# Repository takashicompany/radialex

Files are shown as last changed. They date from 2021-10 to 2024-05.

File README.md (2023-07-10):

# Radialex

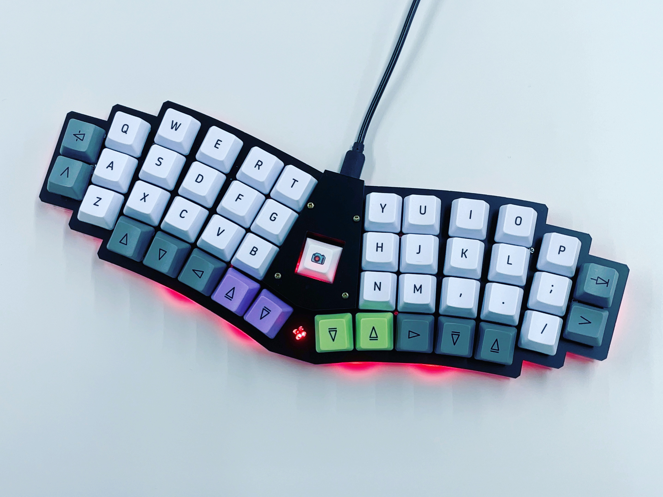
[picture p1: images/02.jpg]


Radialex(ラディアレックス)は一体型の40%のキーボードです。  
放射状に規則的に配置されたキーレイアウトは手を自然な体勢のまま置くことができ、ホームポジションから最短距離で文字を打つことを可能としています。  
キーボードの中央部にはシンボルとしてのキーやキーキャップを配置することができ、またバックライトLEDによるライトアップがされます。  
オプションでMXソケットによるキースイッチの取り替えや、LED、コンスルーにも対応しており、使用するスタイルにあわせた組み立てが可能です。  
また、ファームウェアがVIA(Remap)に対応しているため、Webブラウザからキーマップを書き換えることが可能です。



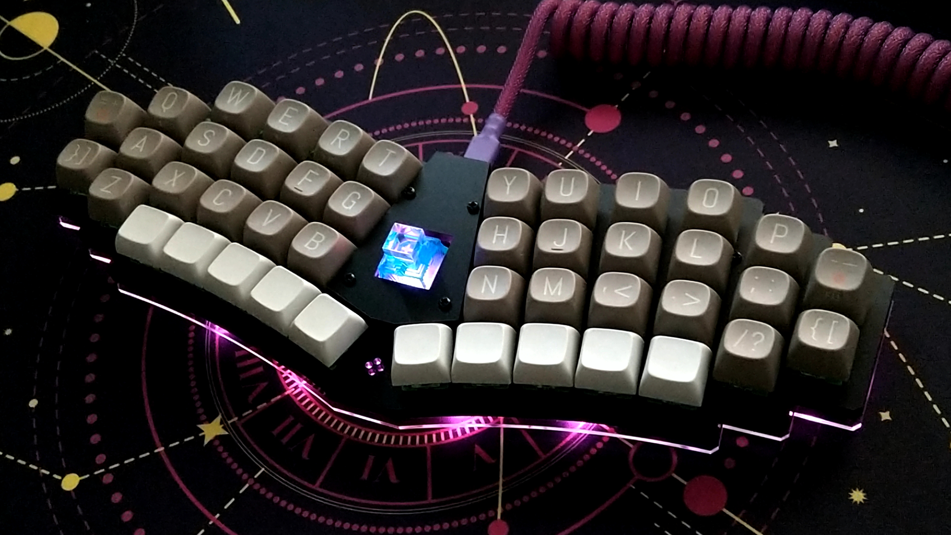
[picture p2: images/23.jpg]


## Store
- [遊舎工房](https://shop.yushakobo.jp/products/3350)
- [Booth](https://takashicompany.booth.pm/items/3394593)

## ガーバーデータ、ケースのデータについて
ご自由にご利用ください。  
尚、ガーバーデータとケースのデータをご自身で利用された際に発生した不都合に関しての責任は負いかねます。

### ガーバーデータやケースを利用した例

[@morecat_lab
](https://twitter.com/morecat_lab)さんの[3Dプリンター製のケース](https://github.com/kuwatay/radialex-3dprint-case)  


## 必要な部品

### キットに同梱されているもの
|部品|個数|備考|
|:--|:--|:--|
|PCB|1|リードタイプと表面実装のダイオードに対応。|
|トッププレート|1||
|ボトムプレート|1||
|中央トッププレート|1||
|中央積層プレート|1||
|表面実装ダイオード|45||
|m2スペーサー(シルバー5mm)|8||
|m2ネジ(シルバー4mm)|8||
|m2ネジ(シルバー8mm)|4||
|m2ネジ(ゴールド18mm)4||
|リセットスイッチ|1||
|キースイッチソケットMX用|1||
|滑り止めシール|6||

### 別途用意するもの
|部品|個数|備考|
|:--|:--|:--|
|キースイッチ|45|Cherry MX互換のもの。|
|キーキャップ|45|全て1u。Chery MX互換のもの。|
|Pro Micro|1||
|USBケーブル|1|Pro MicroとPCを接続します。|

### オプション
|部品|個数|備考|
|:--|:--|:--|
|コンスルー|2|12pin、13pinに対応しておりますのでMCU(Pro Micro)にあわせて選択が可能です。|
|MXソケット|44|中央のキー以外は、キースイッチのはんだ付け/MXソケットによる挿し込みの両方に対応。|
|LED(SK6812MINI-E)|2|中央のキーとキーボード手前側の穴をバックライトで光らせることができます。|
|LED(WS2812B)|10|アンダーグロウライトとしてキーボードの底面を光らせることができます。|

## 組みたて方

[Rev1の組み立て方はこちら](https://github.com/takashicompany/radialex/blob/master/build_rev1.md)

見分け方 : Rev1はPro Microを底面側に取り付けるため、ボトムプレートに切り抜きがあります。  
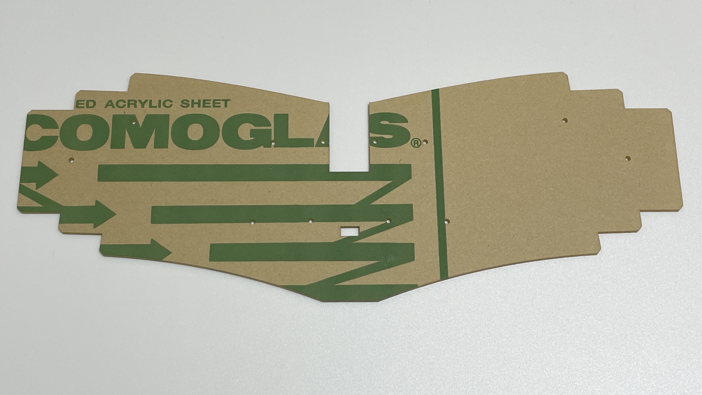
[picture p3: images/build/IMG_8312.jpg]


Rev2以降の組み立て方は以下になります。

### 1. PCBの表裏を確認する

表  
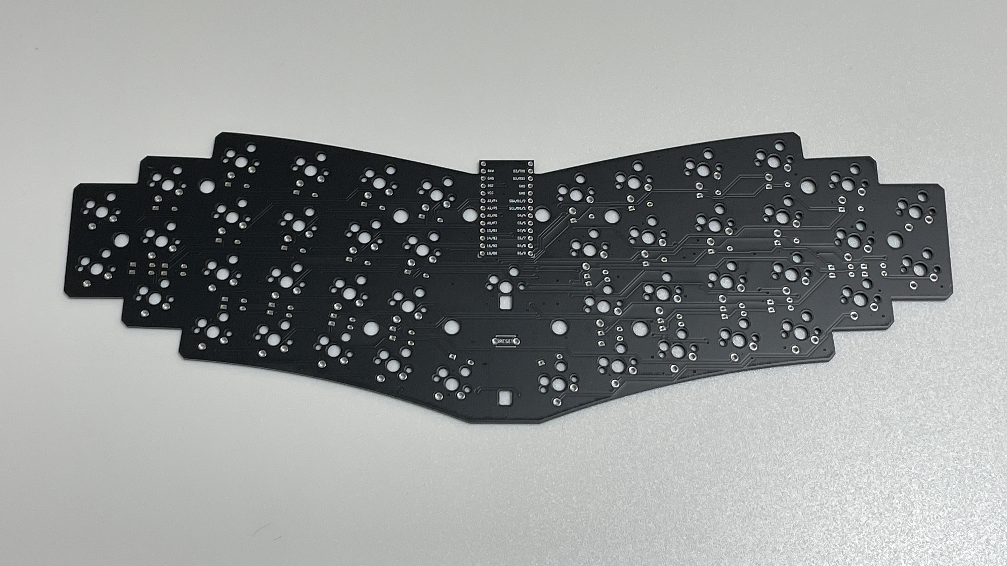
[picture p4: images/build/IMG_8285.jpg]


裏  
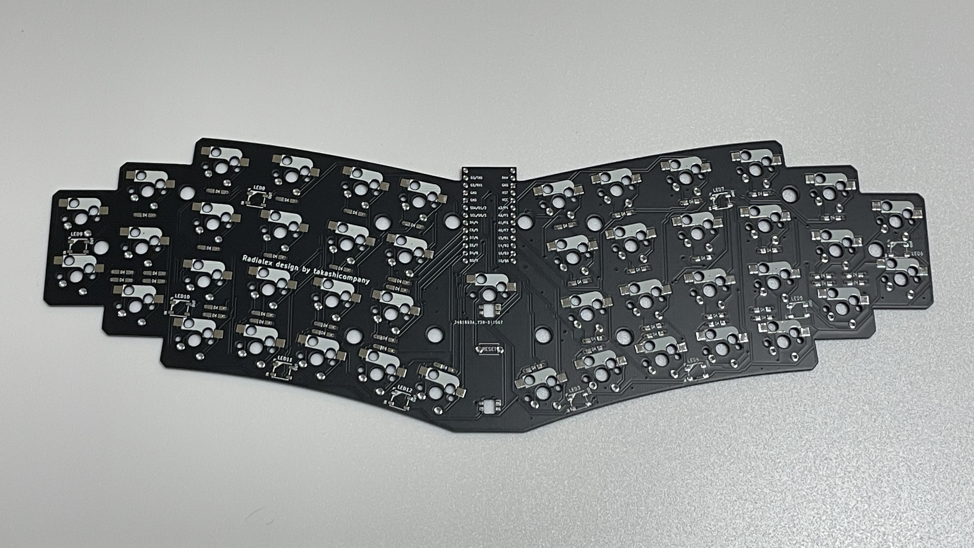
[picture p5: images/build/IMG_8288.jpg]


### 2. ダイオードをはんだづけする

プリントにあわせてダイオードの向き(端に黒線がついているもの)を確認します。  
スルーホール型のダイオード、表面実装型のダイオードの両方に対応しております。

#### スルーホール型のダイオードの場合
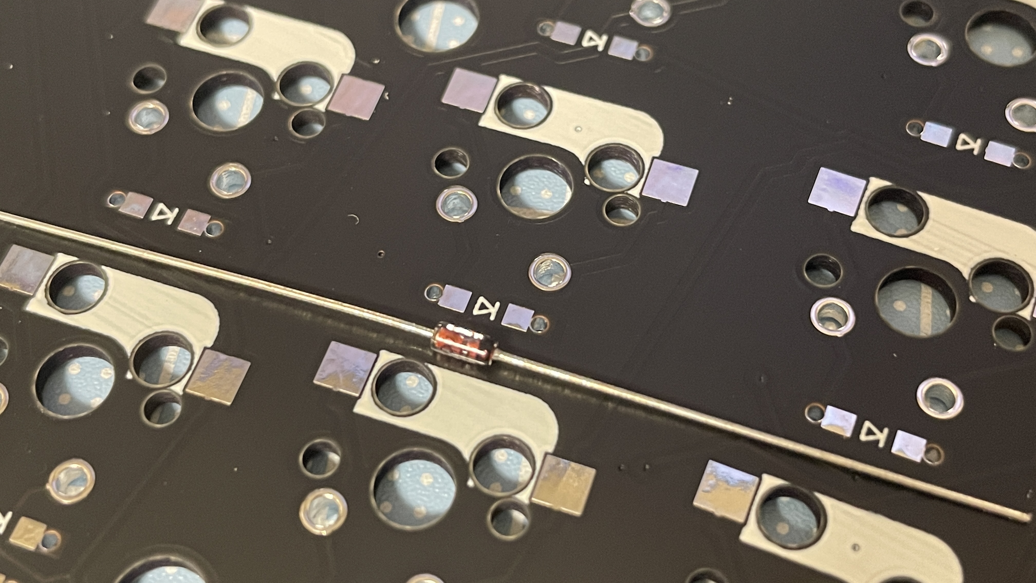
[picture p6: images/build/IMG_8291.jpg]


ダイオードを穴に通るように折り曲げます。  
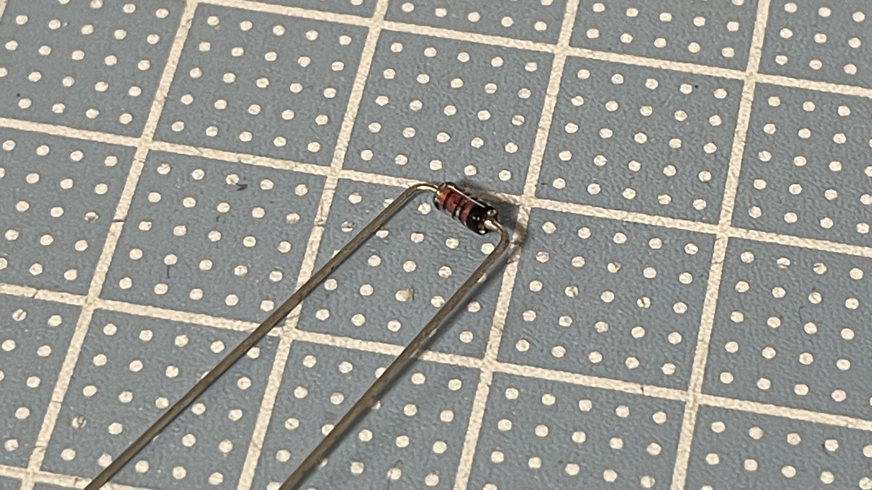
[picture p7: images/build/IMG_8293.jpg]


はんだ付けを行います。  
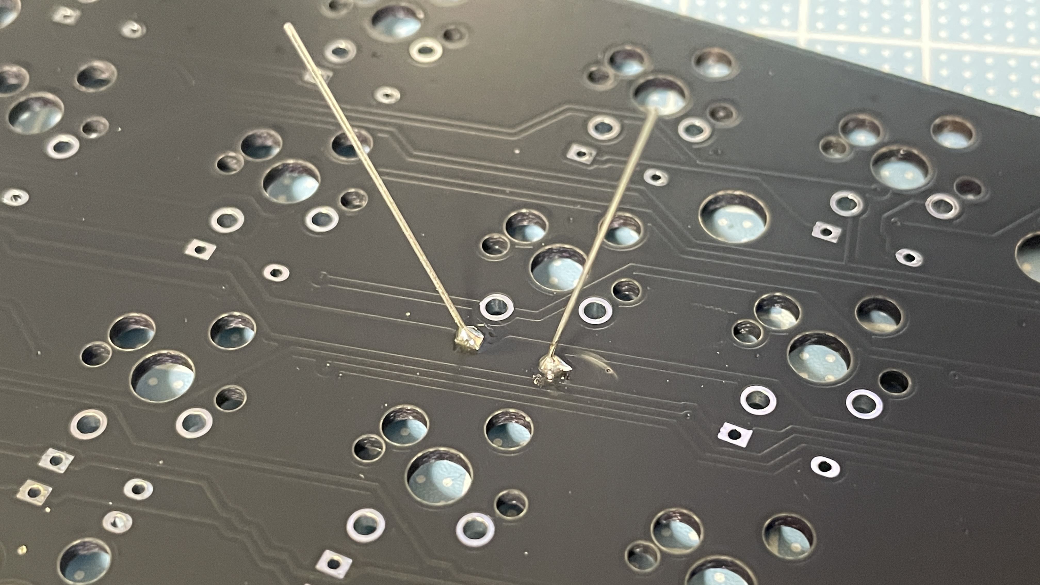
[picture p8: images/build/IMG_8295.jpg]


ニッパーで足を切る際は、可能な限り平坦になるようにすると後の作業が楽に進めます。  
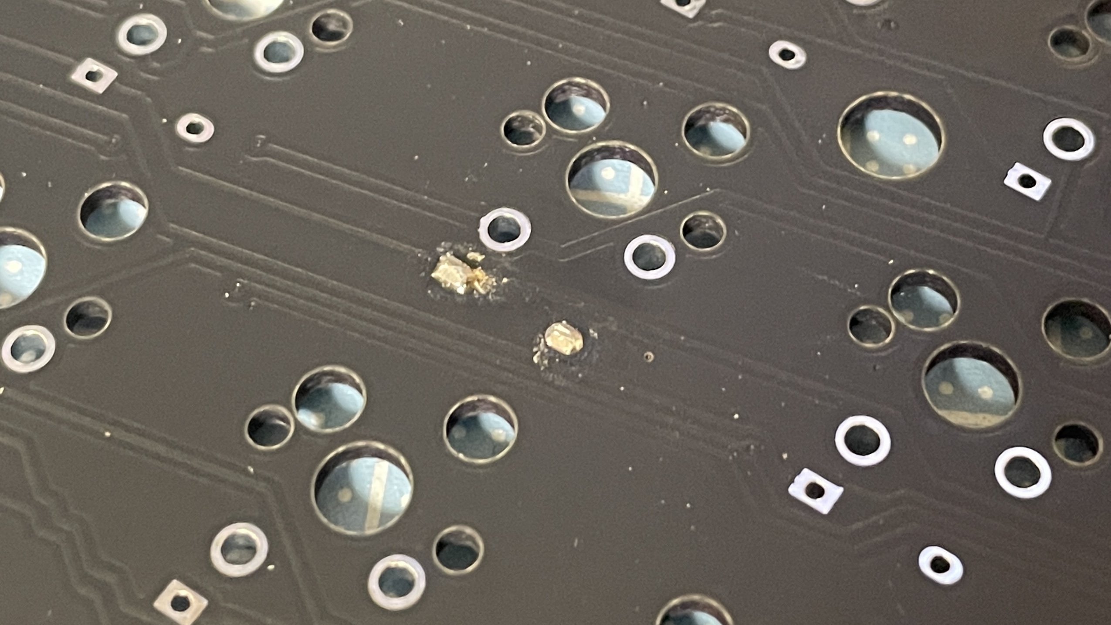
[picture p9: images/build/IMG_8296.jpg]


全部で45箇所となります。  
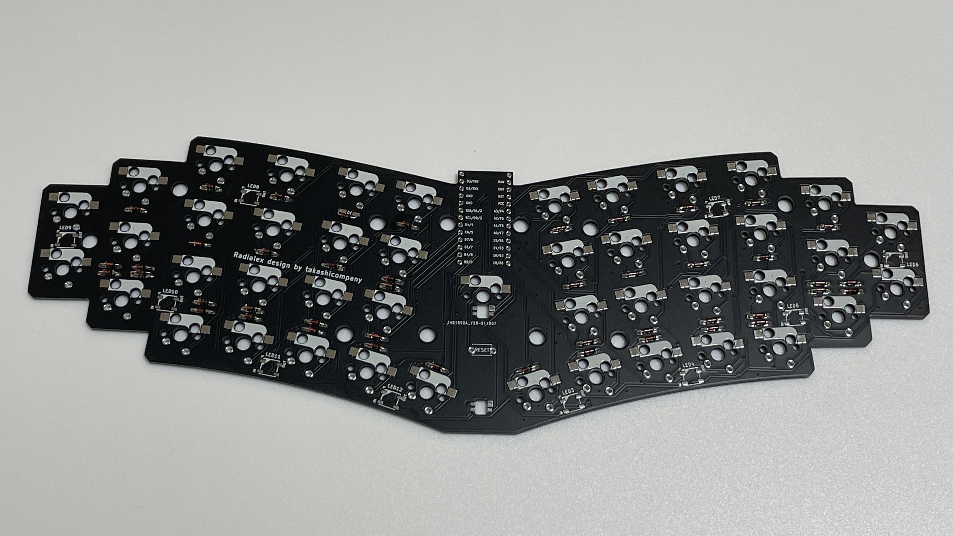
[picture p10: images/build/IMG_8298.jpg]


#### 表面実装型のダイオードの場合

表面実装型のダイオードを使用する場合は表面にはんだが漏れないようにマスキングテープで塞ぎます。  
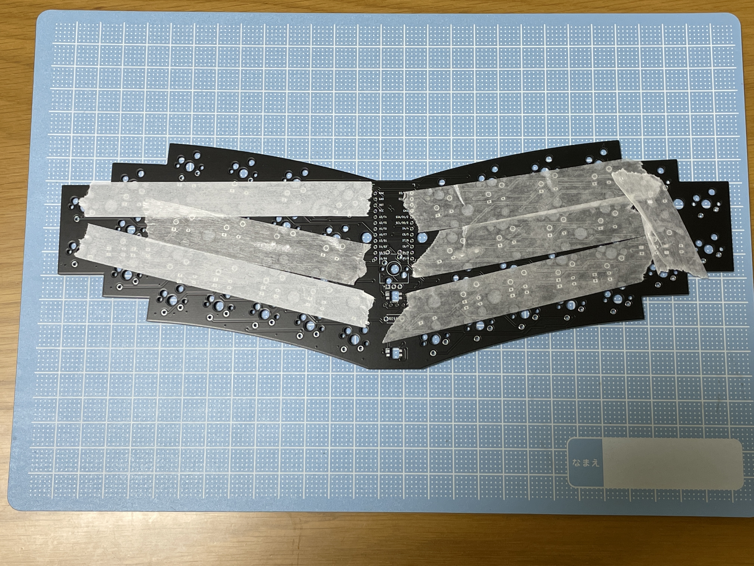
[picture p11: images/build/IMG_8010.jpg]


表面実装型ダイオードのはんだ付けは以下の動画を参考にすると良いかと思います。(PCBが別のキーボードになっておりますが、ご了承ください). 

https://user-images.githubusercontent.com/4215759/126895350-43ae4cd4-408b-4ff4-ab5c-2903e0420978.mov

PCBのダイオードのはんだづけ箇所の片方にはんだを乗せておき(予備はんだ)、ピンセットでダイオードを持ちながら予備はんだを溶かしながらダイオードをはんだづけします。  
片方のはんだづけが終わったら、動画と同じく反対側をはんだづけしましょう。

全部で45箇所となります。  
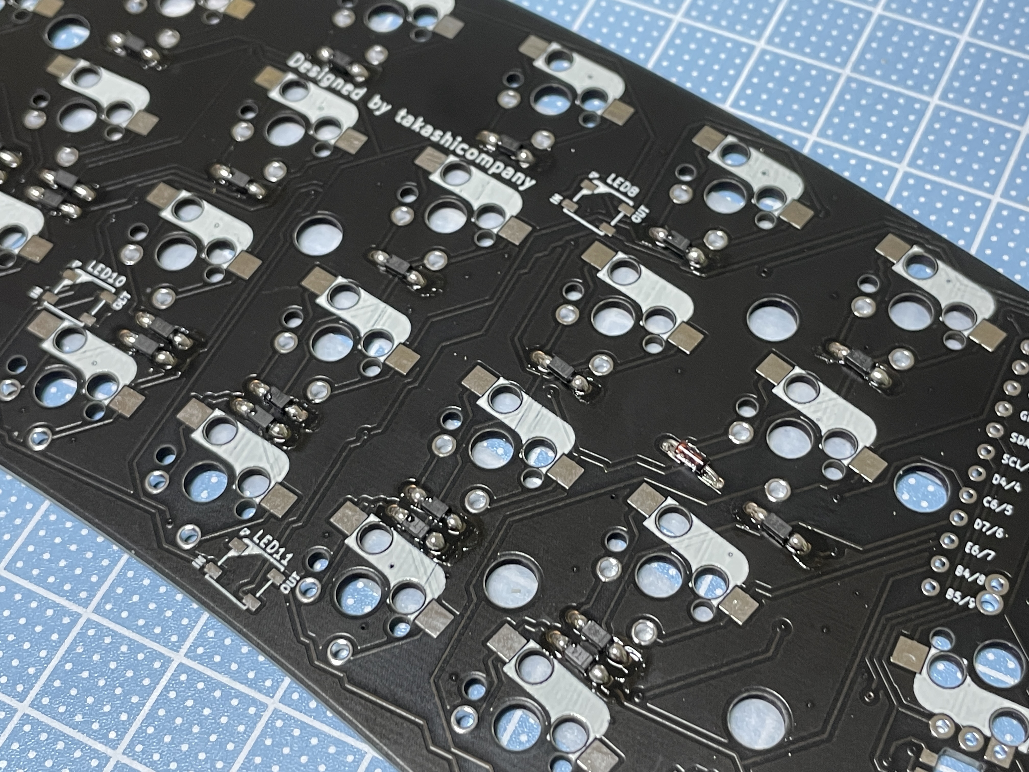
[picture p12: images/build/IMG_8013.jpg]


### 3. 中央のキーのMXソケットの取り付け

中央のキーのみMXソケットでキースイッチを固定します。  
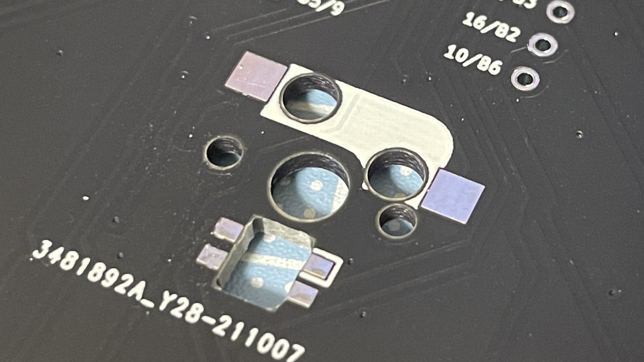
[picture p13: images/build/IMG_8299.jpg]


MXソケット  
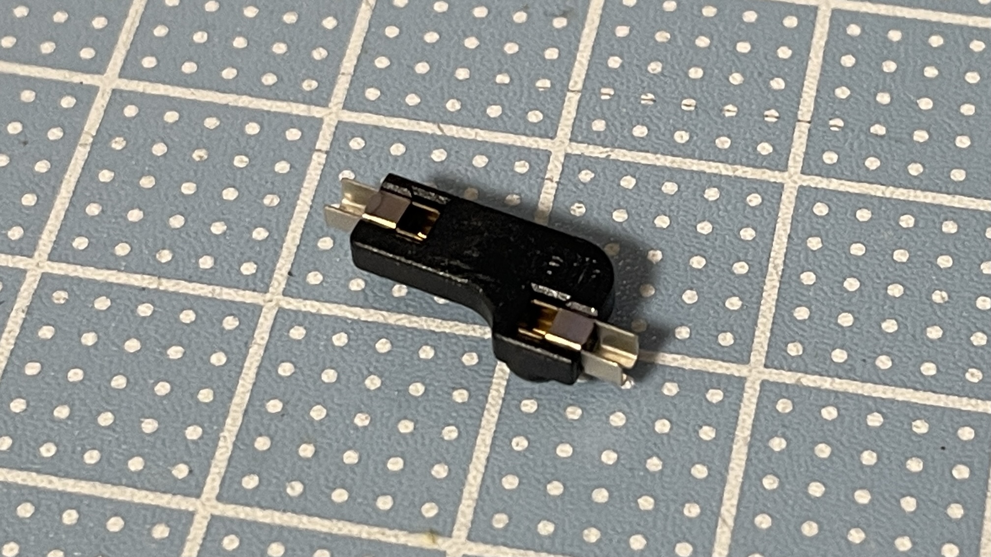
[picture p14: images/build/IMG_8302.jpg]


MXソケットのはんだ付け部分の片方に事前にはんだを載せておきます。  
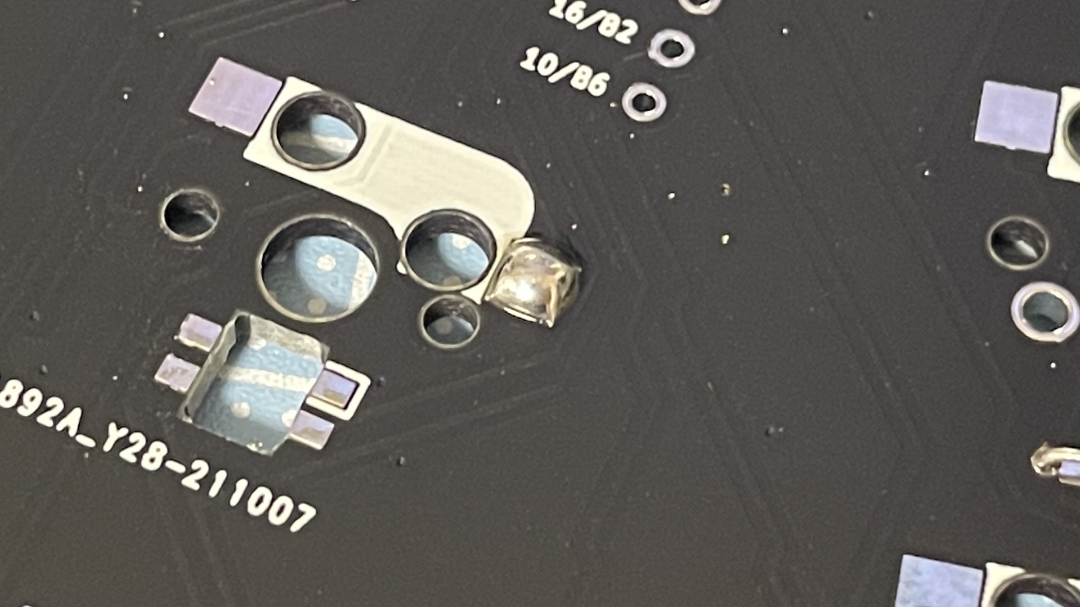
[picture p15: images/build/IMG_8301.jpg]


ピンセットでMXソケットを抑えながら事前に載せたはんだを溶かしながらMXソケットとPCBをはんだ付けします  
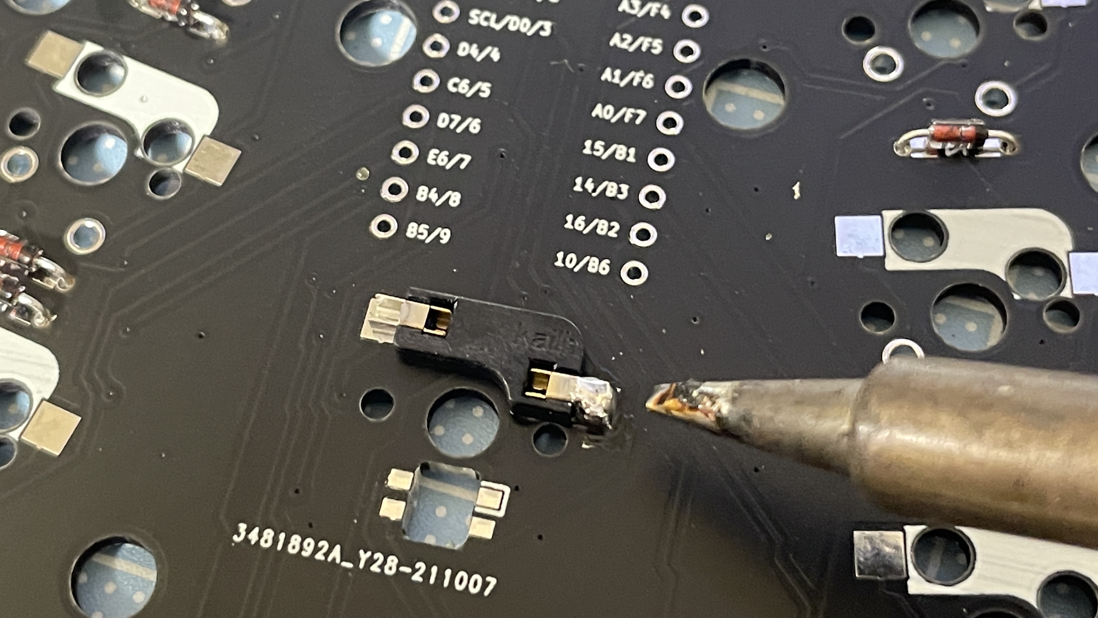
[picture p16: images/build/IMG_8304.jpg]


もう片方もはんだ付けを行います。  
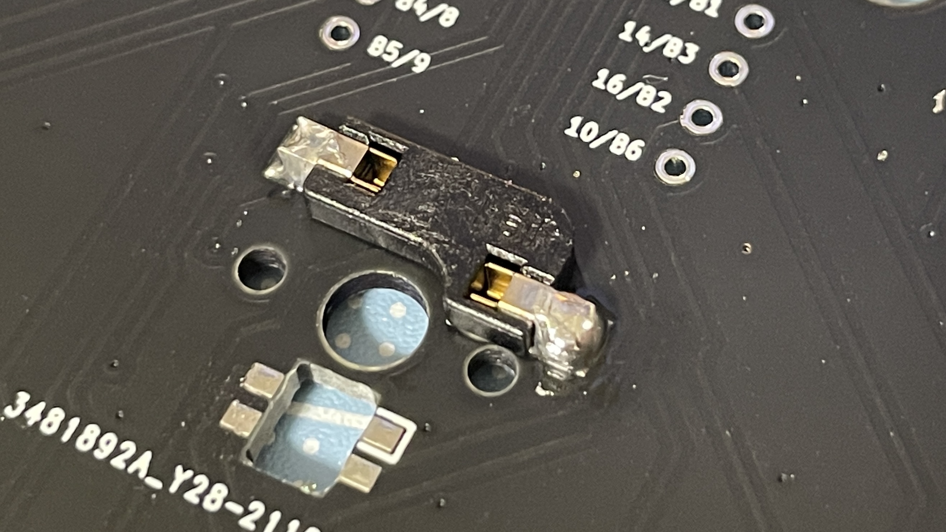
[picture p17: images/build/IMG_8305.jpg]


### 4. リセットスイッチの取り付け

リセットスイッチの取り付け場所はPCBの裏面中央のやや手前側です。  
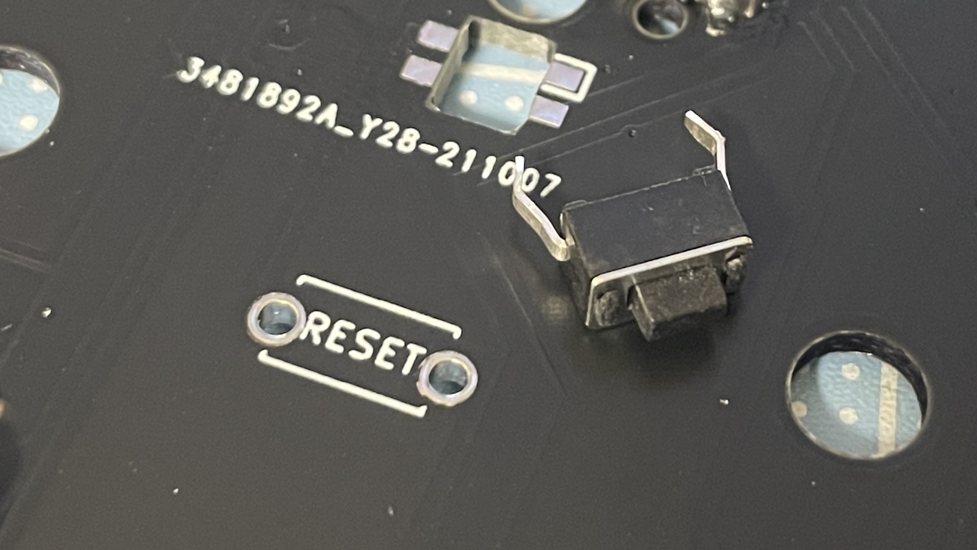
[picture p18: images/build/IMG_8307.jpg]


リセットスイッチがPCBの裏面から押せるように穴に通します。  
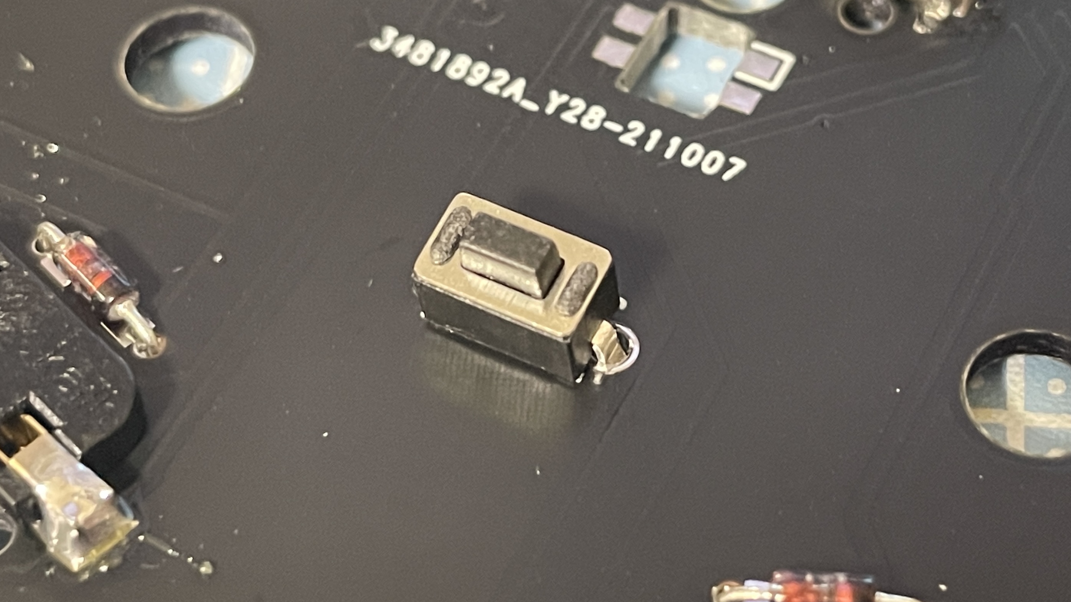
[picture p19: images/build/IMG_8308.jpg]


表面からはんだ付けを行います。この際、可能な限り平坦になるようにニッパーで切ると後の作業がスムーズに行えます。  
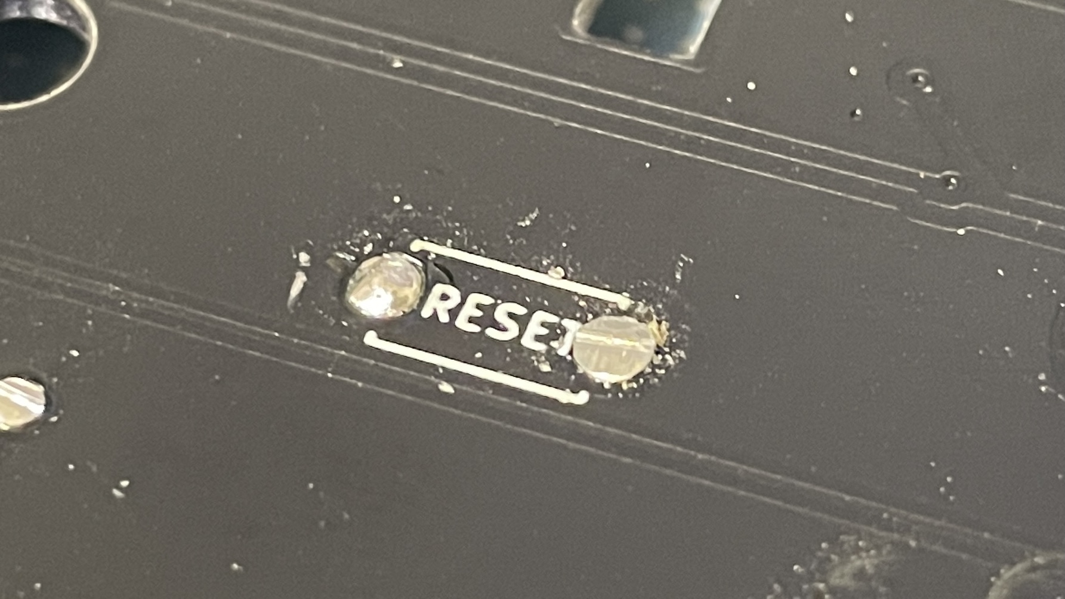
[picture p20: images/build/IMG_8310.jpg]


### 5. トッププレートとキースイッチの取り付け

トッププレートやボトムプレート、中央プレートはアクリルの保護シートが貼ってるので、組み立てる際に剥がしてください。  
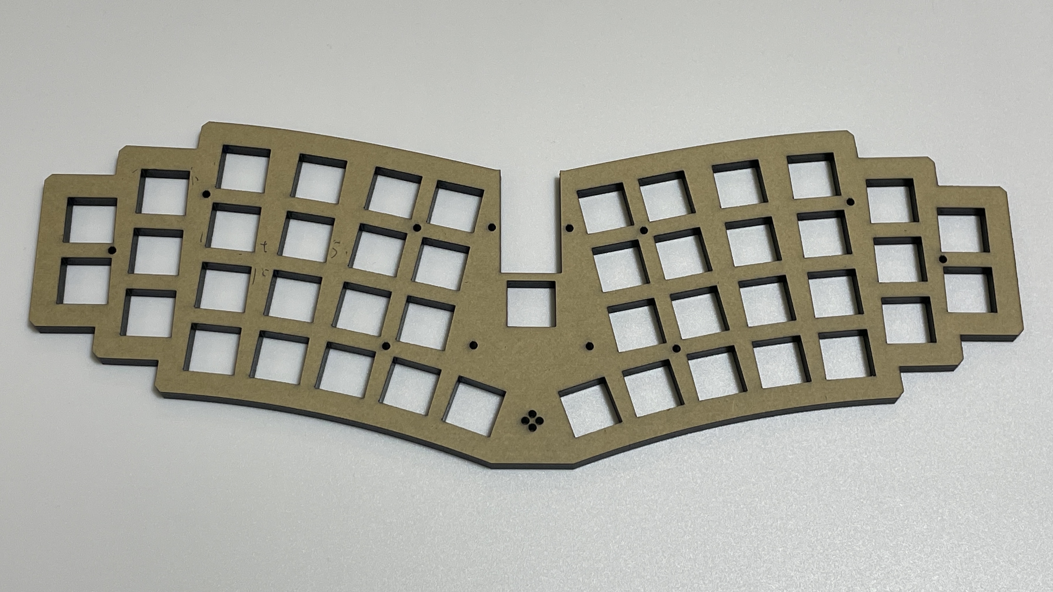
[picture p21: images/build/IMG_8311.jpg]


製造の工程上、模様が発生している可能性がありますが、ご理解いただけますと幸いです。  
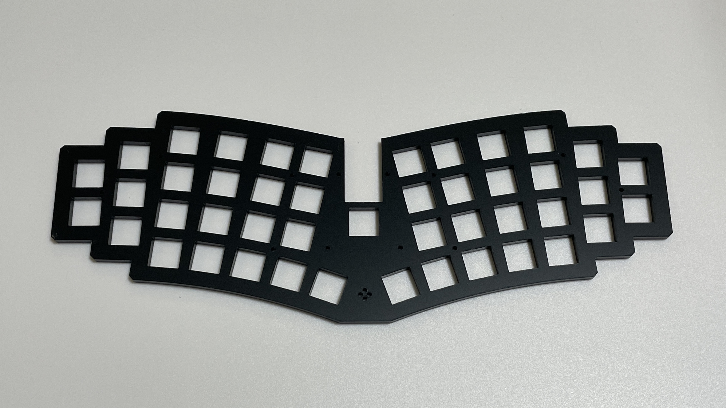
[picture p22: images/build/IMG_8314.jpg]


PCBにトッププレートを載せます。  
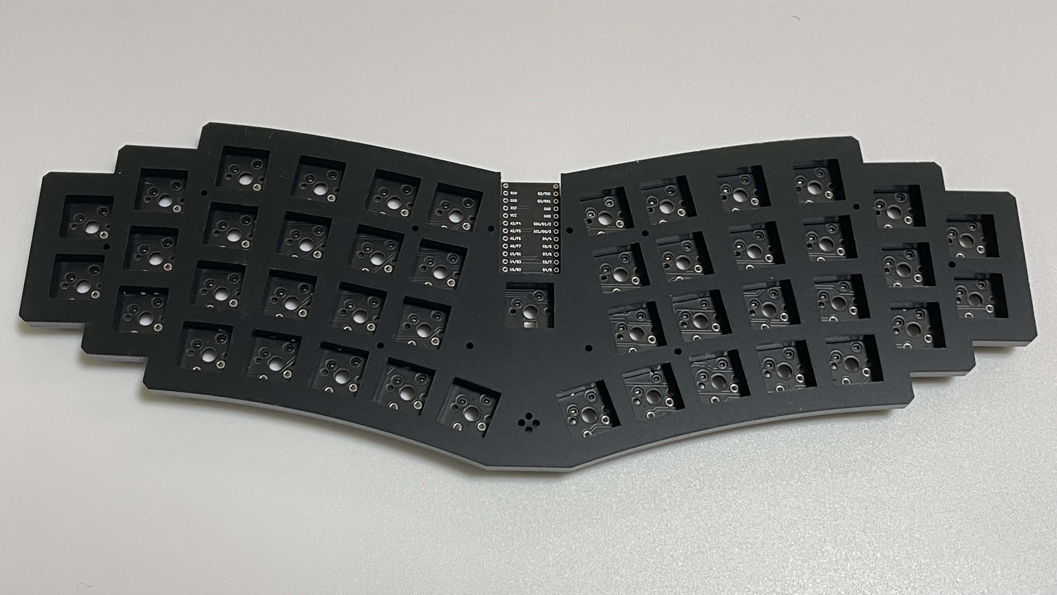
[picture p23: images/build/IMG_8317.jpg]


トッププレートにキースイッチを取り付け、はんだ付けもしくはMXソケットへの差し込みを行います。  
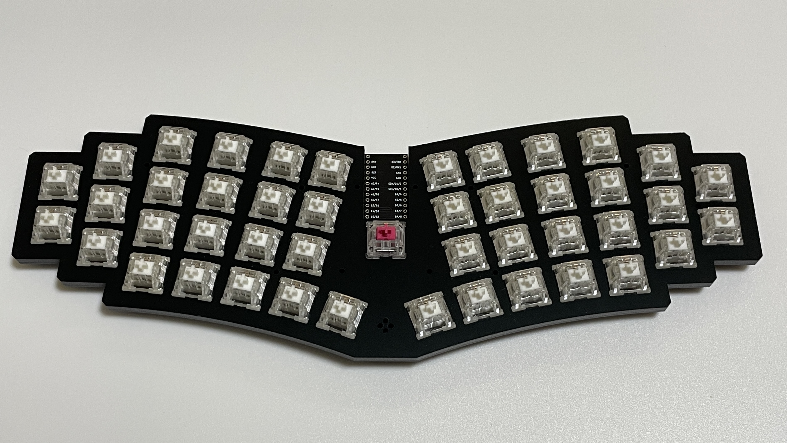
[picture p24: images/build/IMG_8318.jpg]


### 6. Pro Microの取り付け

Pro Microを取り付けます。  
PCBはコンスルーに対応しております。  
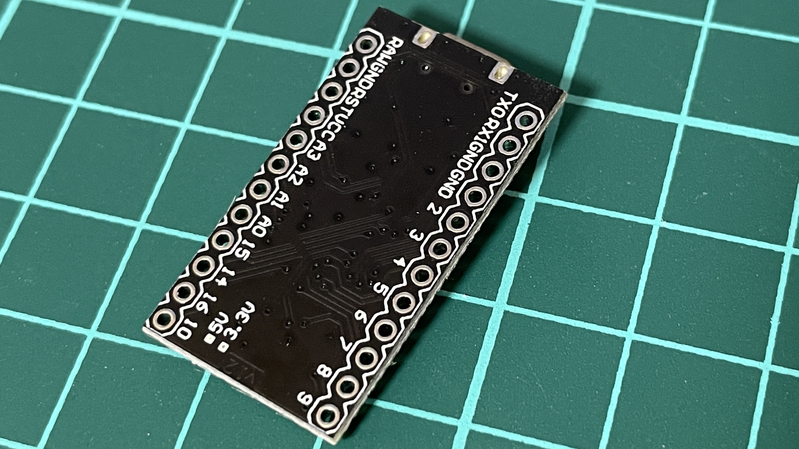
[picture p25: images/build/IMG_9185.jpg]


Pro Microの取り付け位置を確認します。  
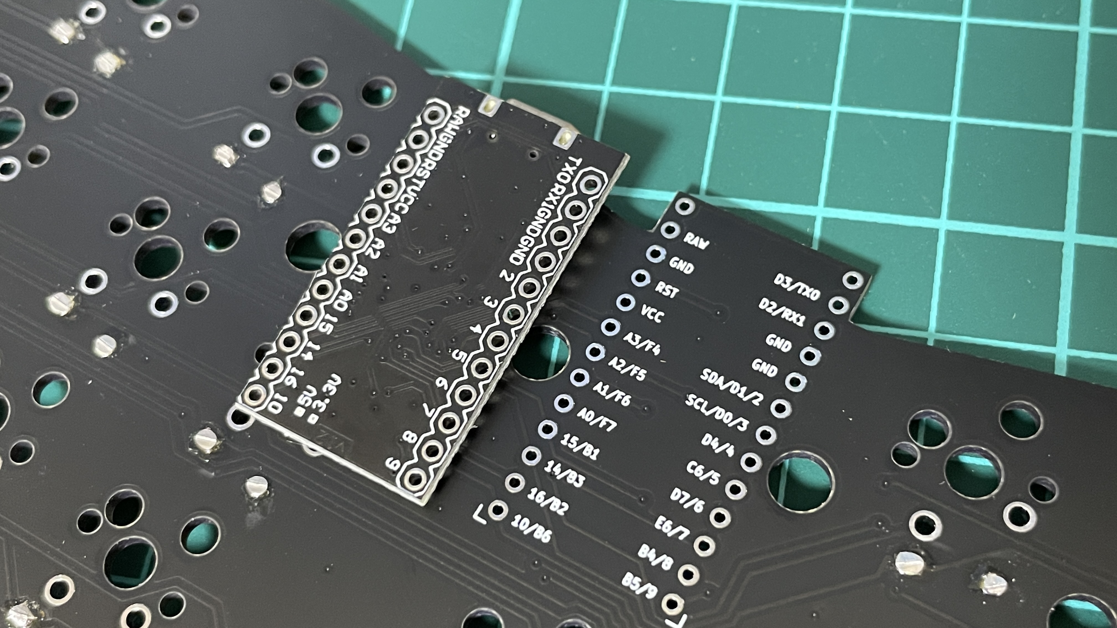
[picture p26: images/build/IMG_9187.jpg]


PCBにピンヘッダ(又はコンスルー)を取り付けます。  
穴は13個ありますが、Pro Microの取り付け穴は12個なので、1つ余ります。  
Pro Microの印字とPCBの印字が合うように挿してください。  
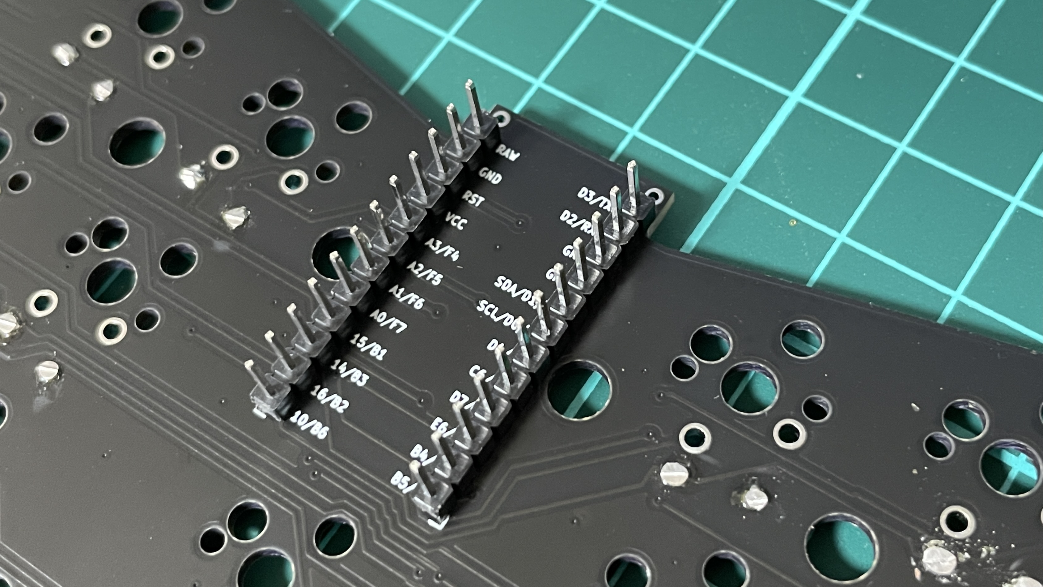
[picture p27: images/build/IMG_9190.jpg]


ピンヘッダ(コンスルー)にPro Microを挿してはんだ付けをします。  
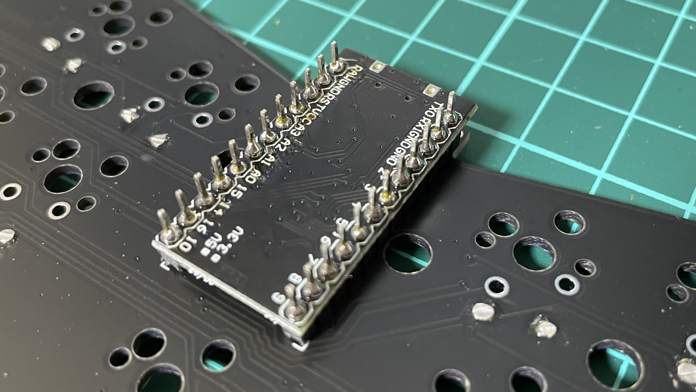
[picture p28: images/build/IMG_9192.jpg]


ピンの余った部分はニッパーで切ります。    
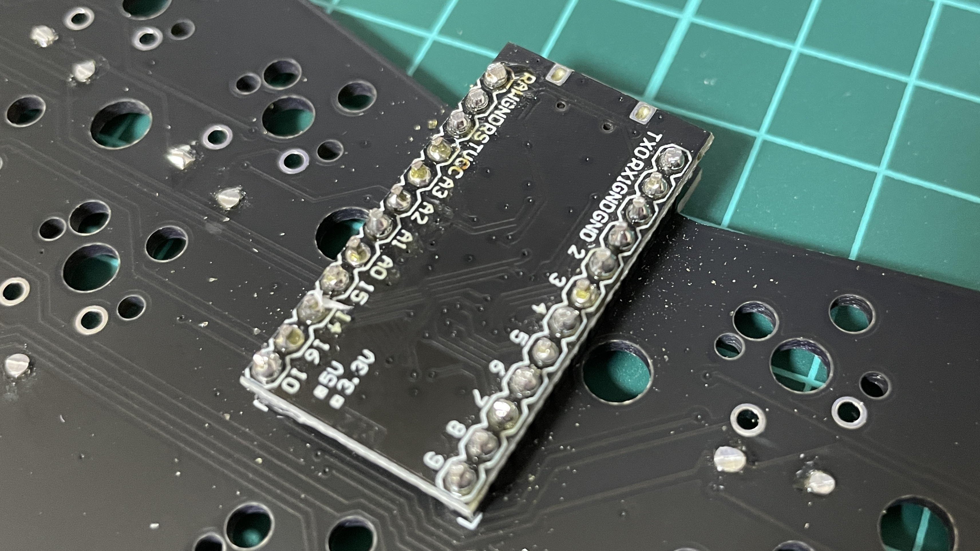
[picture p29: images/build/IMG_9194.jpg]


ピンヘッダの場合は裏面からはんだ付けを行います。  
(コンスルーの場合は、PCBとのはんだ付けをしなくて大丈夫です)
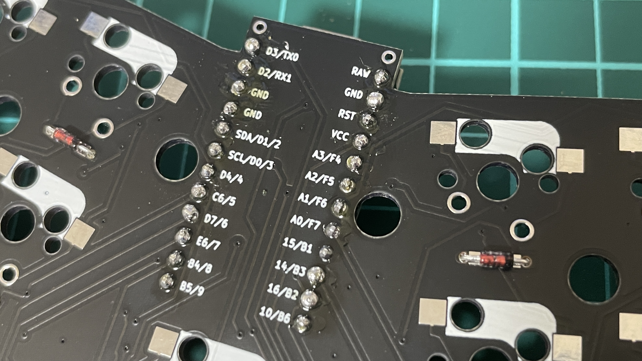
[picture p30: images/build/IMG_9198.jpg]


### 7. 中央プレートの取り付け

中央プレートは二種類あります。  
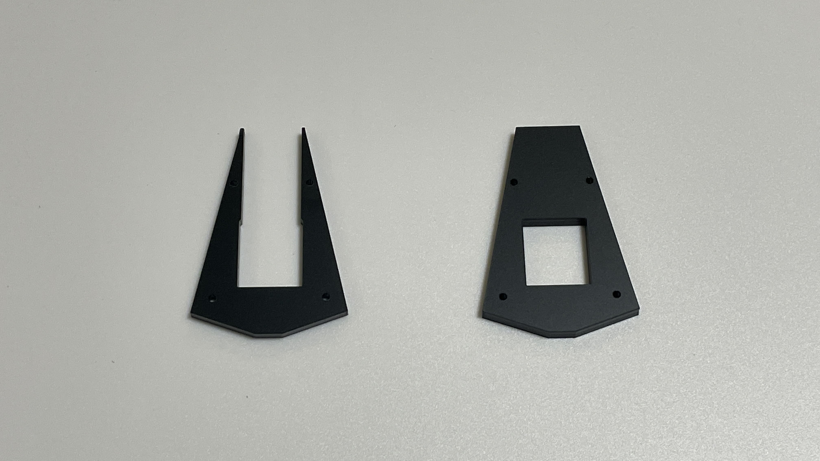
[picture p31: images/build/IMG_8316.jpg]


18mmのネジとスペーサーを用います。  
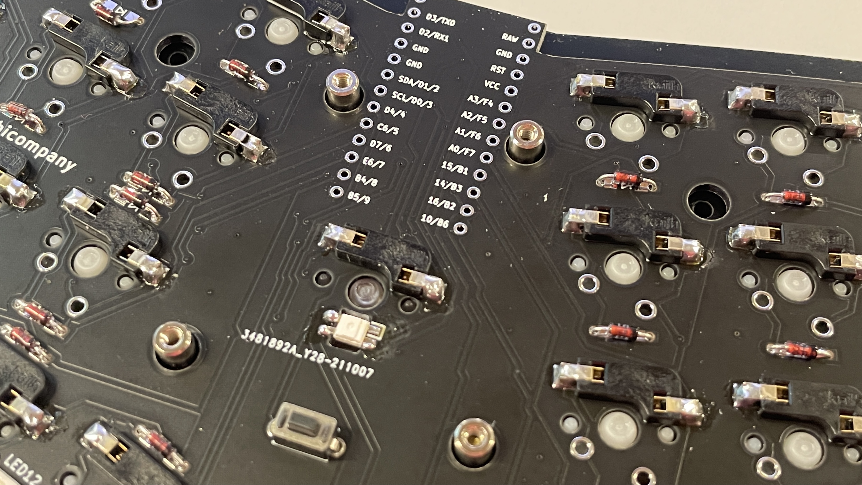
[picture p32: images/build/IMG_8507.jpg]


PCBの裏側から、スペーサーでネジと中央プレートを取り付けます。  
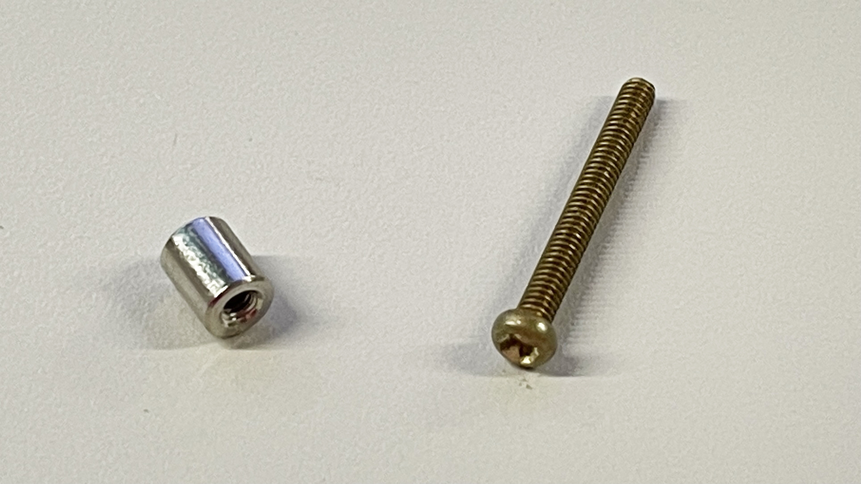
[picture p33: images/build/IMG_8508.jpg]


表面は下図のようになります。  
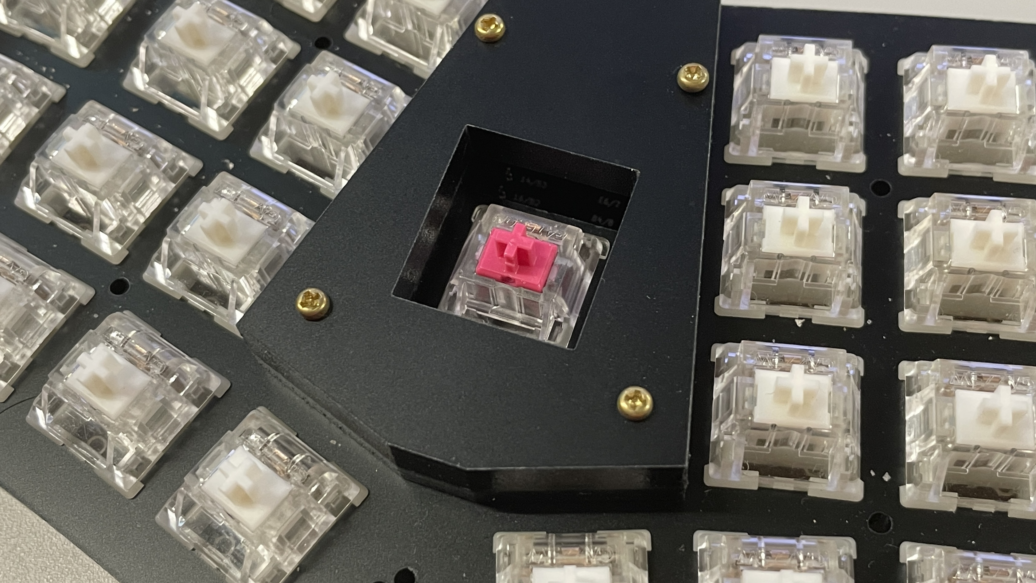
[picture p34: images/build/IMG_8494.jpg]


### 8. ファームウェアの用意と確認

[Remap](https://remap-keys.app/catalog/IxsMPjShxAP0NbiQGbKQ/firmware)からVIAのファームウェアを書き込むことが可能です。  


Remapの使い方は[千葉千夏/あずさんの記事](https://note.com/azulee/n/n8557fdfbc679#MkVkQ)で説明されております。

ファームウェアのソースコードは[こちら](https://github.com/qmk/qmk_firmware/pull/14949)です。

VIAのファームウェアを書き込んだ状態で[Remap](https://remap-keys.app/)からキーマップを変更できます。  


### 9. LEDの取り付け(オプション)

Radialexでは、2種類のLEDを搭載できます。  
1-2番はバックライト(SK6812MINI-E)、3番から12番まではアンダーグロウ(WS2812B)となります。  
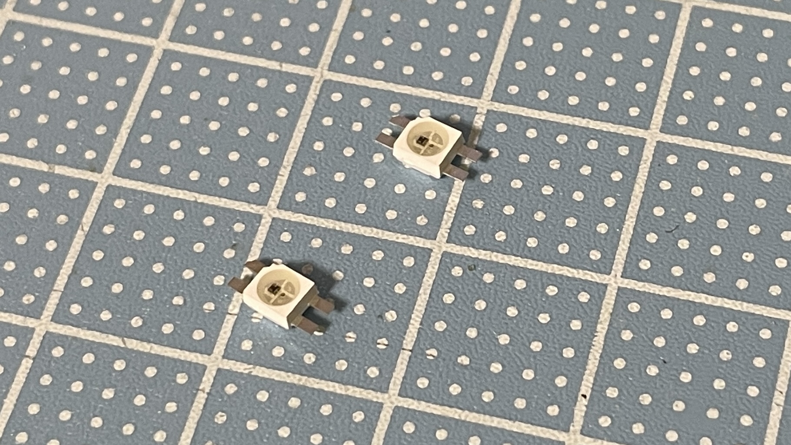
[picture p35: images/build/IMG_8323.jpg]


バックライトのLEDを付ける際はシルクで塗られたところにGND(LEDの角が欠けている部分)が来るように配置します。  
事前にはんだを乗せておくのが良いです。  
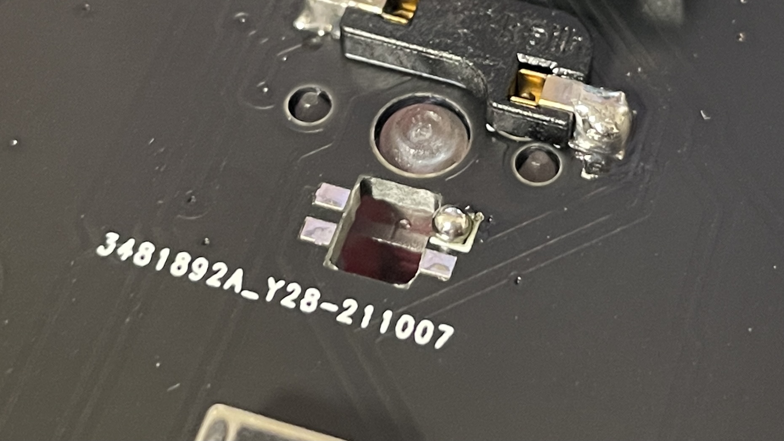
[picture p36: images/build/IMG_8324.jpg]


4箇所をはんだ付けします。  
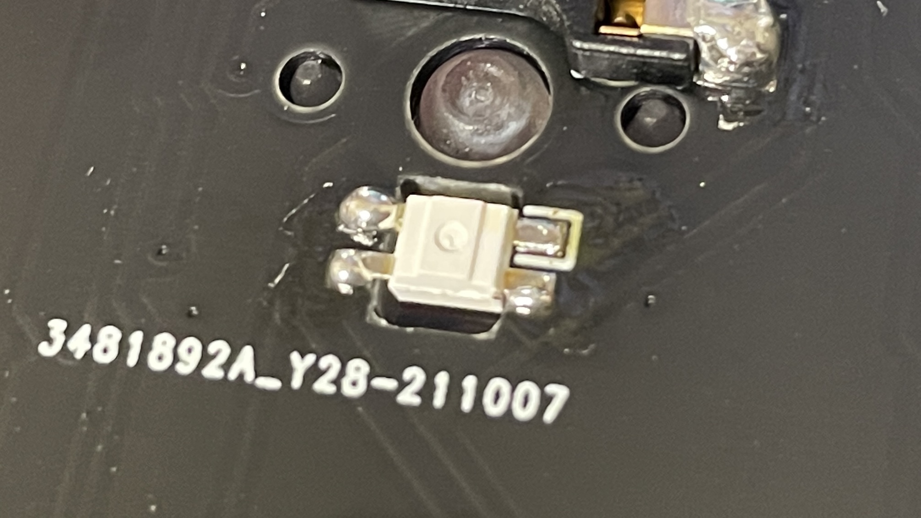
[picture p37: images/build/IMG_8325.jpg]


中央のキースイッチと手前の穴が光ります。  
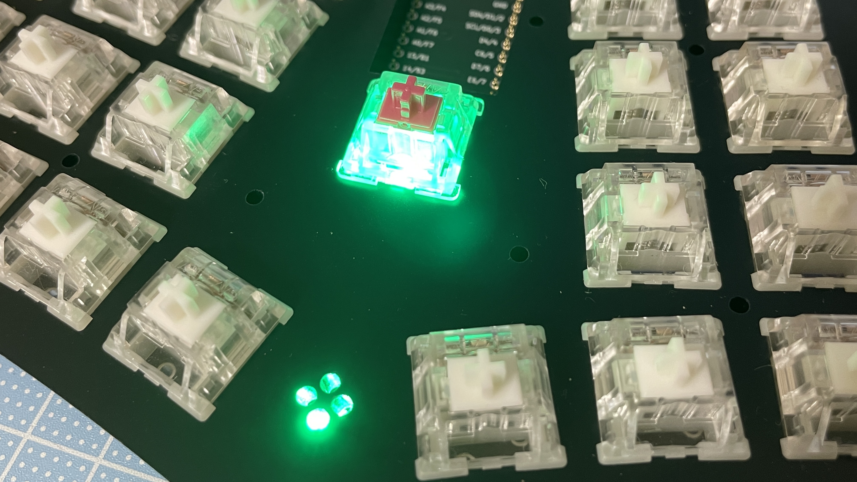
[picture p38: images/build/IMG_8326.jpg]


アンダーグロウも同様に、シルクの三角の部分にGND(LEDが角が欠けている部分)が来るように配置します。  
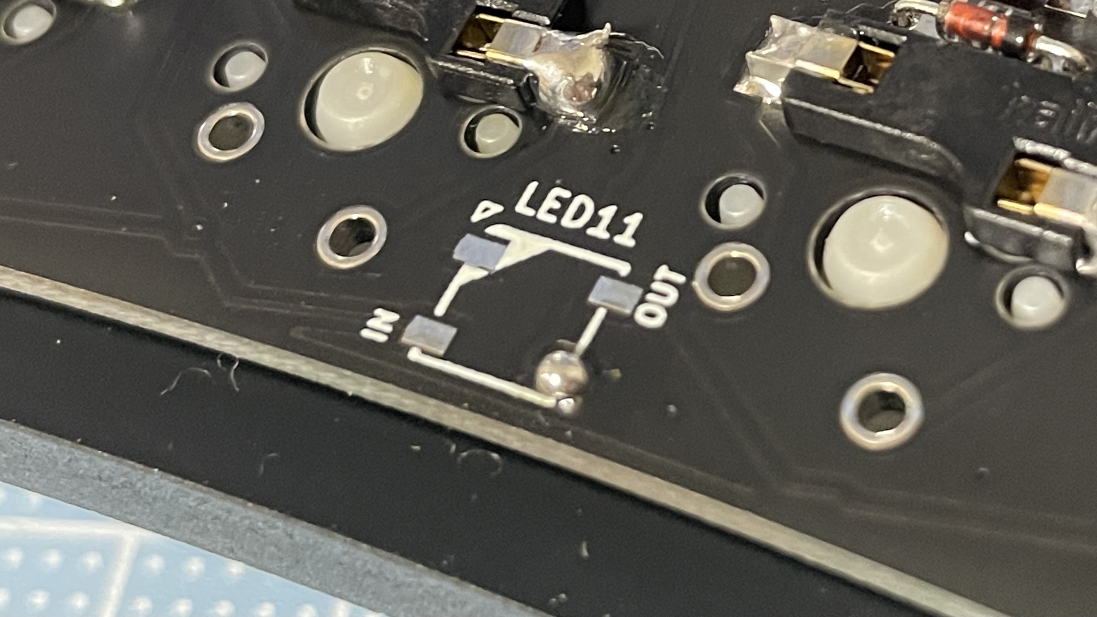
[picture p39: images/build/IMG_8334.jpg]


同じく4箇所をはんだ付けします。  
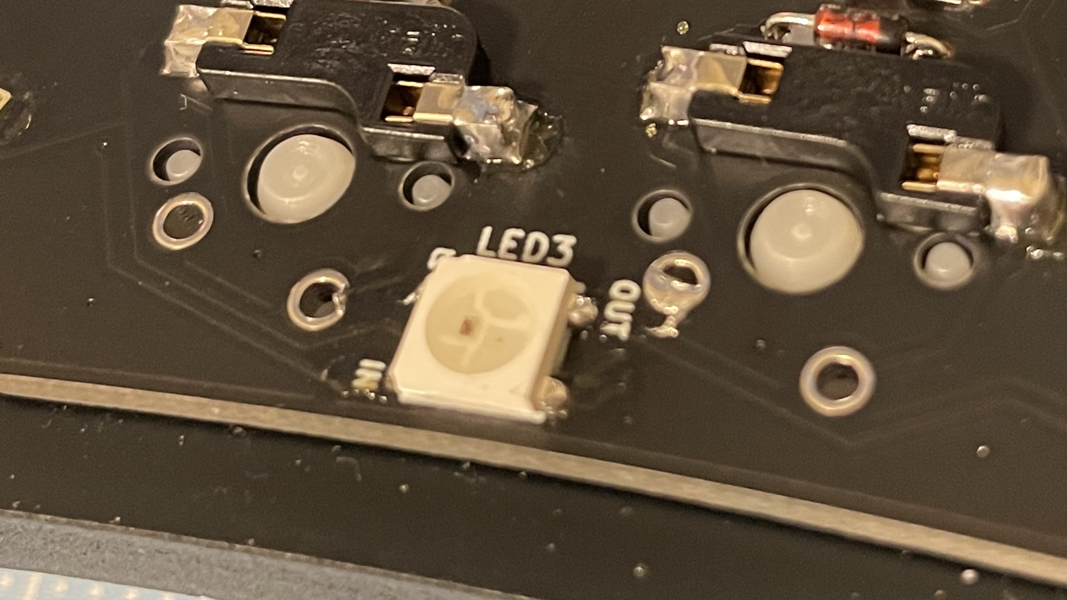
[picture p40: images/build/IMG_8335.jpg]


12箇所が光るかを確認します。  


### 10. ボトムプレートの取り付け

最後にボトムプレートを取り付けます。  


トッププレート側は8mmのネジ、ボトムプレート側は4mmのネジでスペーサーを赤丸の位置に留めます。  


ボトムプレートを取り付けたら滑り止めシールを底面に取り付けます。


赤丸の位置に貼るとグラつきが少ないです。  


### 11. キーキャップを取り付ける

最後にキーキャップを取り付けて完成です。  


### 12. 自慢する
完成しましたら、ぜひSNSなどに写真を投稿頂ければと思います。  
Twitterのハッシュタグは`#Radialex`を付けていただけば幸いです。  
キットを組み立てた感想や、キーボードを使った所感などをお待ちしております！  

また、毎週日曜日の１9時より実施されている[#KEEP_PD](https://twitter.com/hashtag/KEEB_PD?f=live)に投稿頂くこともオススメです。  
開催の告知は[@KEEB_PD](https://twitter.com/KEEB_PD)にて行われております。

ご不明な点などございましたら、[@takashicompany](https://twitter.com/takashicompany)にメンションやDM頂ければと思います！

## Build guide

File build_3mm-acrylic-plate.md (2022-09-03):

# アクリル3mmケースバージョン

[遊舎工房さん](https://shop.yushakobo.jp/)の[自作キーボードオープンソースPCB](https://shop.yushakobo.jp/products/oss_pcb?variant=44403999539431)と[キーボードアクリルプレートサービス](https://shop.yushakobo.jp/collections/services/products/keyboard_acrylic_plate?variant=44150778986727)を利用することで、お好きなカラーのRadialexを作ることが可能です。
場合によってはお手頃な値段でRadialexをつくることが可能です。

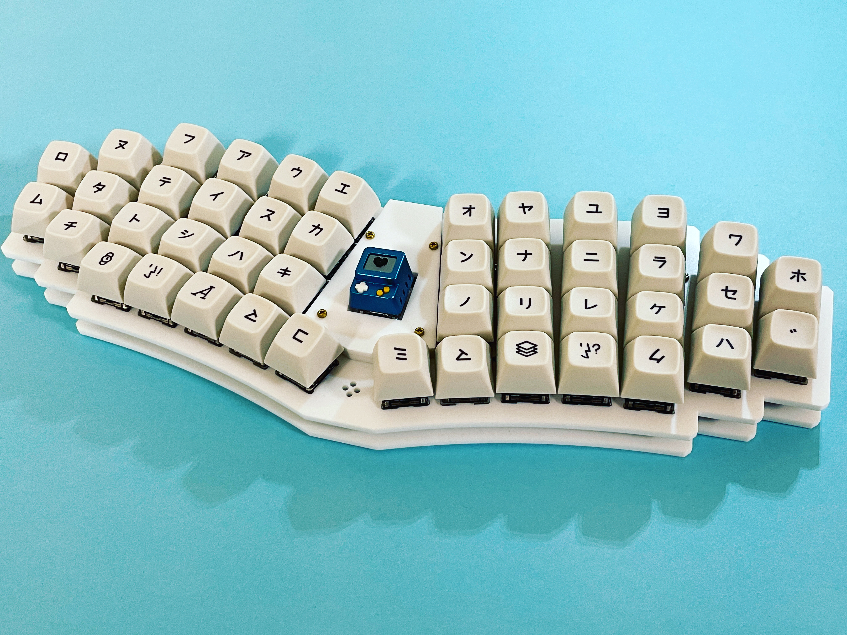
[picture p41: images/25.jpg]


アクリルケースの.aiデータは[こちら](https://github.com/takashicompany/radialex/raw/master/case/radialex-yusha-Laser_A4.ai)になります。

### キット相当の部品
|部品|必要個数|リンクと値段|備考|
|:--|:--|:--|:--|
|[Radialex PCB](https://shop.yushakobo.jp/products/oss_pcb?variant=44403999539431)|1|¥1,100||
|[アクリルケース](https://shop.yushakobo.jp/collections/services/products/keyboard_acrylic_plate?variant=44150778986727)|1|¥3,830~||
|[ダイオード](https://shop.yushakobo.jp/collections/all-keyboard-parts/Diode)|45|¥220|アクリル3mmプレートの場合は[リードタイプ](https://shop.yushakobo.jp/collections/all-keyboard-parts/products/a0800di-01-100)、[SMDタイプ](https://shop.yushakobo.jp/collections/all-keyboard-parts/products/a0800di-02-100)のどちらにも対応。|
|[m2スペーサー(7mm)](https://shop.yushakobo.jp/collections/all-keyboard-parts/products/a0800c2?variant=37665435222177)|8|¥396||
|[m2ネジ(5mm)](https://shop.yushakobo.jp/collections/all-keyboard-parts/products/a0800n2?variant=37665432993953)|12|¥220||
|m2ネジ([8mm](https://shop.yushakobo.jp/collections/all-keyboard-parts/products/a0800n2?variant=37665433026721) or 10mm)|4|¥220|8mmネジを使った場合は[中央プレートの取り付け](https://github.com/takashicompany/radialex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)は1枚のみ。10mmのネジで2枚取り付け可能。|
|[タクタイルスイッチ 2pin](https://shop.yushakobo.jp/collections/all-keyboard-parts/products/a0800ts-01-1)|1||¥11||
|[Kailh スイッチソケット(MX用)](https://shop.yushakobo.jp/collections/all-keyboard-parts/products/a01ps)|1~45|¥187|最低1つは必要。全てのキースイッチをソケット化する場合は45個必要|
|[ウレタンクッション](https://shop.yushakobo.jp/products/a0800ur-01-6?)|6|¥132|6個でも正しく貼れば安定しますが、不安な方は2セット買っておくことを推奨します。|

### 組み立ての際にご自身で用意が必要なもの
|部品|必要個数|備考|
|:--|:--|:--|
|[Cherry MX（互換）スイッチ](https://shop.yushakobo.jp/collections/all-switches/cherry-mx-%E4%BA%92%E6%8F%9B-%E3%82%B9%E3%82%A4%E3%83%83%E3%83%81)|45||
|[Cherry MX（互換）キーキャップ](https://shop.yushakobo.jp/collections/keycaps/cherry-mx-%E4%BA%92%E6%8F%9B-%E3%82%AD%E3%83%BC%E3%82%AD%E3%83%A3%E3%83%83%E3%83%97)|45|全て1u。Chery MX(互換)スイッチ軸に対応するもの。|
|[Pro Micro](https://shop.yushakobo.jp/collections/all-keyboard-parts/products/pro-micro)|1||
|USBケーブル|1|Pro MicroとPCを接続します。|

### より一層オシャレに・使いやすくするために
|部品|個数|備考|
|:--|:--|:--|
|[コンスルー](https://shop.yushakobo.jp/products/31)|2|取り付けるとMCU(Pro Micro)をPCBから取り外すことが可能です。PCBは12pinと13pinに対応しておりますのでMCUのピン数にあわせて選択してください。|
|[LED(SK6812MINI-E)](https://shop.yushakobo.jp/collections/all-keyboard-parts/products/sk6812mini-e-10)|2|中央のキーとキーボード手前側の穴をバックライトで光らせることができます。|
|[LED(WS2812B)](https://shop.yushakobo.jp/collections/all-keyboard-parts/products/a0800ws-01-10)|10|アンダーグロウライトとしてキーボードの底面を光らせることができます。|

### 組み立て方

基本的には[通常版のRadialexの組み立て方](https://github.com/takashicompany/radialex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)と同様です。
(一部部品は、通常版と異なります。)

[Daihuku Keyboard](https://www.youtube.com/c/DaihukuKeyboard)さんの[自作キーボード作ってみた Radialex編](https://www.youtube.com/watch?v=C8Qqe03oXgY)をご覧になるとより理解が深まるかと思います。

ご留意いただきたい点としましては、低コスト化のためボトムプレートの一部をくり抜いております。  
使用には問題ないかと思いますが、通常版とは打鍵感などが異なる可能性があります。  


### 免責事項

当キーボードビルドガイドにて組み立てた際に生じた不利益や責任は組み立てたご自身に帰属します。

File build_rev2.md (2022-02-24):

# Radialex Rev2の組み立て方

## [Rev1](https://github.com/takashicompany/radialex/blob/master/build_rev1.md)との違い
- Pro Microの取り付け位置をPCBの表面にしています。
- 一部の説明画像はRev1のものを流用しておりますが、Pro Microの取り付け以外の工程は同様に進めていただければ問題ございません。
## 必要な部品

### キットに同梱されているもの
|部品|個数|備考|
|:--|:--|:--|
|PCB|1|リードタイプと表面実装のダイオードに対応。|
|トッププレート|1||
|ボトムプレート|1||
|中央トッププレート|1||
|中央積層プレート|1||
|ダイオード|45||
|m2スペーサー(5mm)|8||
|m2ネジ(4mm)|8||
|m2ネジ(8mm)|4||
|m2ネジ(18mm)4||
|リセットスイッチ|1||
|MXソケット|1||
|滑り止めシール|6||

### 別途用意するもの
|部品|個数|備考|
|:--|:--|:--|
|キースイッチ|45|Cherry MX互換のもの。|
|キーキャップ|45|全て1u。Chery MX互換のもの。|
|Pro Micro|1||
|USBケーブル|1|Pro MicroとPCを接続します。|

### オプション
|部品|個数|備考|
|:--|:--|:--|
|コンスルー|2|12pin、13pinに対応しておりますのでMCU(Pro Micro)にあわせて選択が可能です。|
|MXソケット|44|中央のキー以外は、キースイッチのはんだ付け/MXソケットによる挿し込みの両方に対応。|
|LED(SK6812MINI-E)|2|中央のキーとキーボード手前側の穴をバックライトで光らせることができます。|
|LED(WS2812B)|10|アンダーグロウライトとしてキーボードの底面を光らせることができます。|

## 組みたて方

### 1. PCBの表裏を確認する

表  


裏  


### 2. ダイオードをはんだづけする

プリントにあわせてダイオードの向き(端に黒線がついているもの)を確認します。  
スルーホール型のダイオード、表面実装型のダイオードの両方に対応しております。  


ダイオードを穴に通るように折り曲げます。  


はんだ付けを行います。  


ニッパーで足を切る際は、可能な限り平坦になるようにすると後の作業が楽に進めます。  


全部で45箇所となります。  


### 3. 中央のキーのMXソケットの取り付け

中央のキーのみMXソケットでキースイッチを固定します。  


MXソケット  


MXソケットのはんだ付け部分の片方に事前にはんだを載せておきます。  


ピンセットでMXソケットを抑えながら事前に載せたはんだを溶かしながらMXソケットとPCBをはんだ付けします  


もう片方もはんだ付けを行います。  


### 4. リセットスイッチの取り付け

リセットスイッチの取り付け場所はPCBの裏面中央のやや手前側です。  


リセットスイッチがPCBの裏面から押せるように穴に通します。  


表面からはんだ付けを行います。この際、可能な限り平坦になるようにニッパーで切ると後の作業がスムーズに行えます。  


### 5. トッププレートとキースイッチの取り付け

トッププレートやボトムプレート、中央プレートはアクリルの保護シートが貼ってるので、組み立てる際に剥がしてください。  


製造の工程上、模様が発生している可能性がありますが、ご理解いただけますと幸いです。  


PCBにトッププレートを載せます。  


トッププレートにキースイッチを取り付け、はんだ付けもしくはMXソケットへの差し込みを行います。  


### 6. Pro Microの取り付け

Pro Microを取り付けます。  
PCBはコンスルーに対応しております。  


Pro Microの取り付け位置を確認します。  


PCBにピンヘッダ(又はコンスルー)を取り付けます。  
穴は13個ありますが、Pro Microの取り付け穴は12個なので、1つ余ります。  
Pro Microの印字とPCBの印字が合うように挿してください。  


ピンヘッダ(コンスルー)にPro Microを挿してはんだ付けをします。  


ピンの余った部分はニッパーで切ります。    


ピンヘッダの場合は裏面からはんだ付けを行います。  
(コンスルーの場合は、PCBとのはんだ付けをしなくて大丈夫です)


### 7. 中央プレートの取り付け

中央プレートは二種類あります。  


18mmのネジとスペーサーを用います。  


PCBの裏側から、スペーサーでネジと中央プレートを取り付けます。  


表面は下図のようになります。  


### 8. ファームウェアの用意と確認

[Remap](https://remap-keys.app/catalog/IxsMPjShxAP0NbiQGbKQ/firmware)からVIAのファームウェアを書き込むことが可能です。  


Remapの使い方は[千葉千夏/あずさんの記事](https://note.com/azulee/n/n8557fdfbc679#MkVkQ)で説明されております。

ファームウェアのソースコードは[こちら](https://github.com/qmk/qmk_firmware/pull/14949)です。

VIAのファームウェアを書き込んだ状態で[Remap](https://remap-keys.app/)からキーマップを変更できます。  


### 9. LEDの取り付け(オプション)

Radialexでは、2種類のLEDを搭載できます。  
1-2番はバックライト(SK6812MINI-E)、3番から12番まではアンダーグロウ(WS2812B)となります。  


バックライトのLEDを付ける際はシルクで塗られたところにGND(LEDの角が欠けている部分)が来るように配置します。  
事前にはんだを乗せておくのが良いです。  


4箇所をはんだ付けします。  


中央のキースイッチと手前の穴が光ります。  


アンダーグロウも同様に、シルクの三角の部分にGND(LEDが角が欠けている部分)が来るように配置します。  


同じく4箇所をはんだ付けします。  


12箇所が光るかを確認します。  
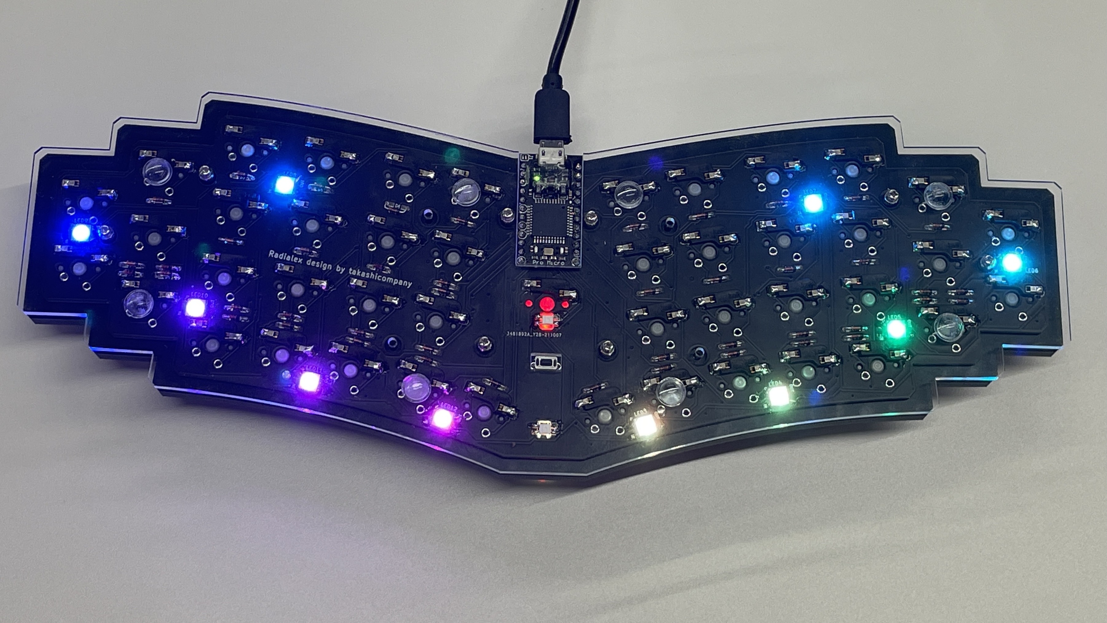
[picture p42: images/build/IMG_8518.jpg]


### 10. ボトムプレートの取り付け

最後にボトムプレートを取り付けます。  


トッププレート側は8mmのネジ、ボトムプレート側は4mmのネジでスペーサーを赤丸の位置に留めます。  
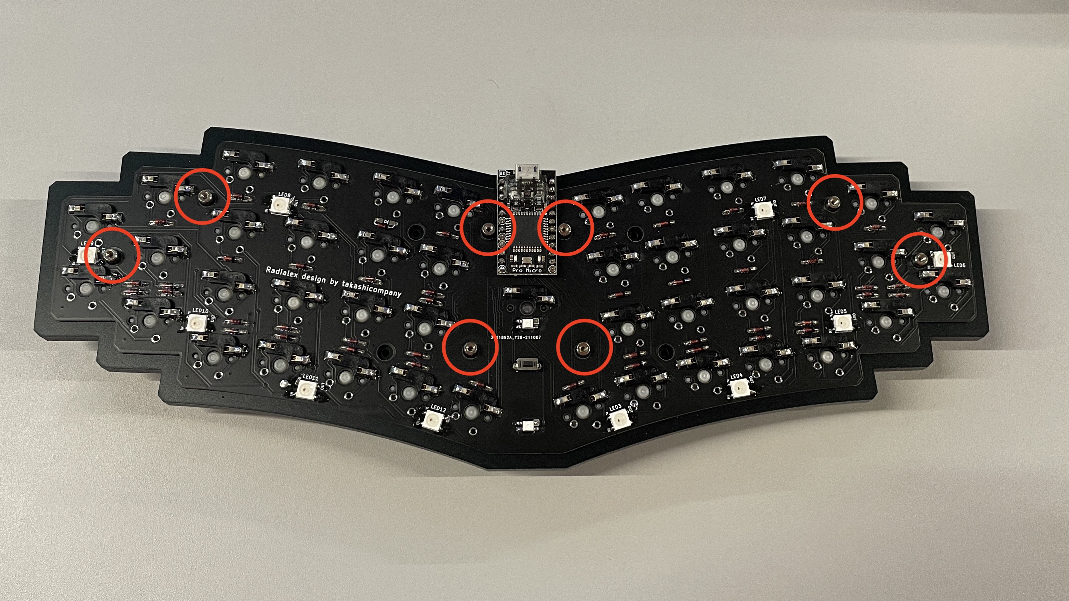
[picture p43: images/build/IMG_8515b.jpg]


ボトムプレートを取り付けたら滑り止めシールを底面に取り付けます。
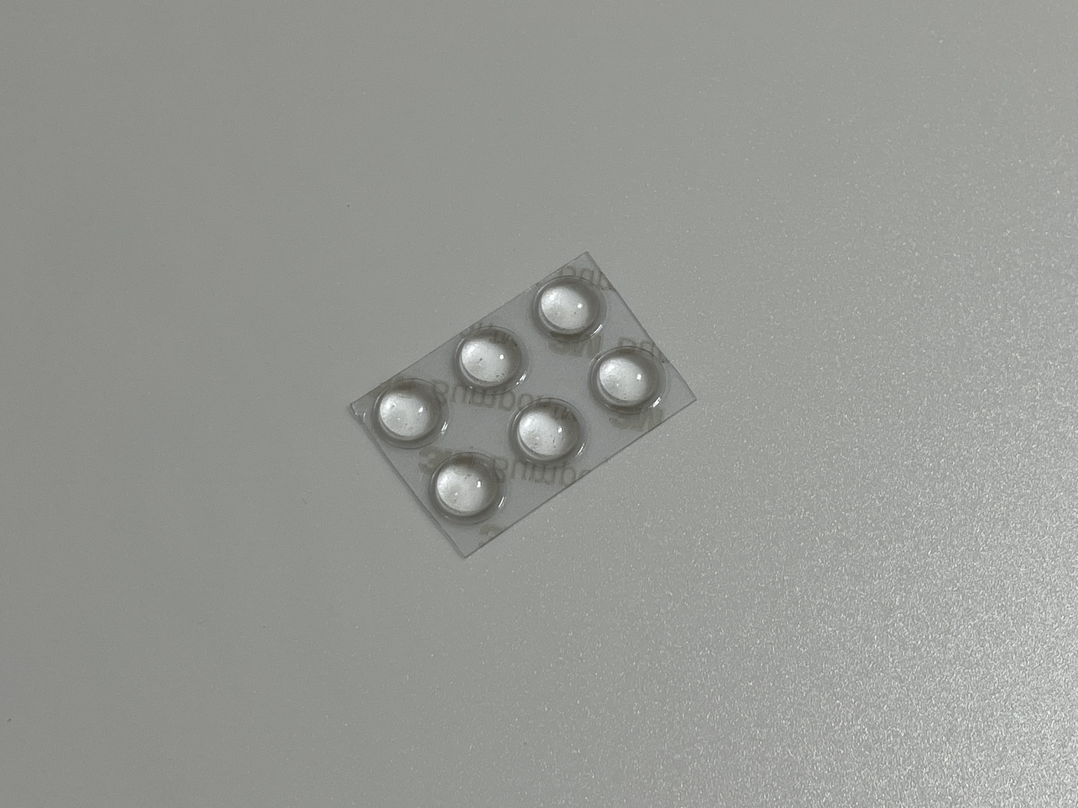
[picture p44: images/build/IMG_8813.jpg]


赤丸の位置に貼るとグラつきが少ないです。  
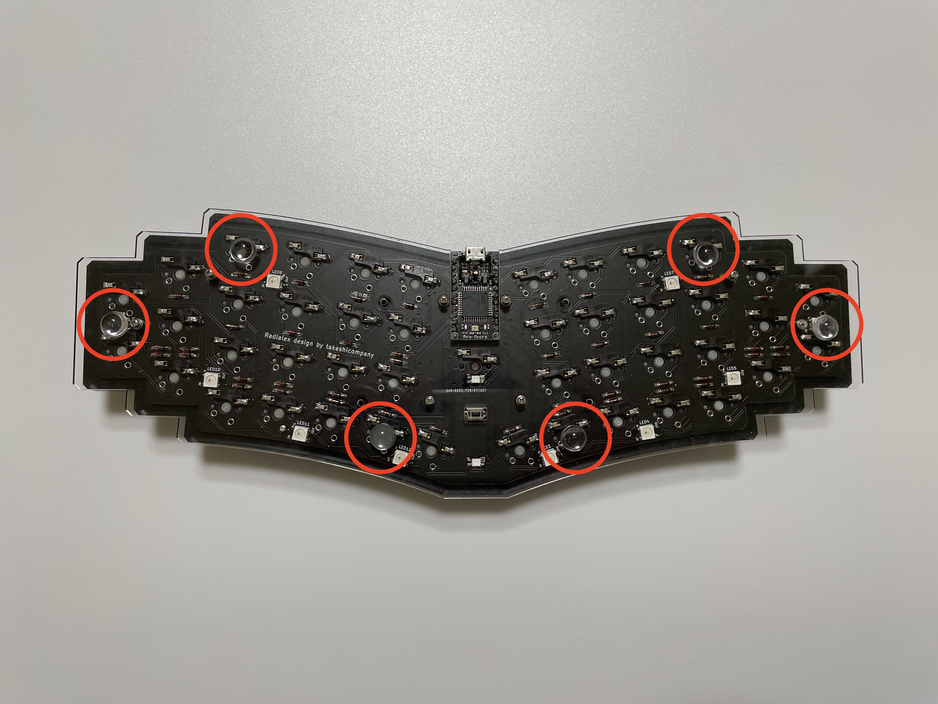
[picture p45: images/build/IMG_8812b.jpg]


### 11. キーキャップを取り付ける

最後にキーキャップを取り付けて完成です。  
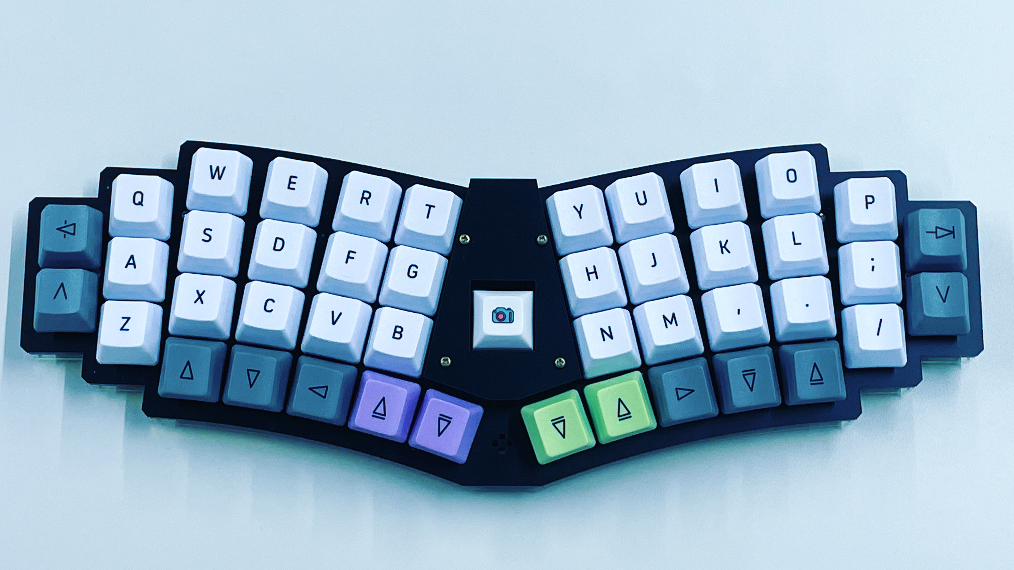
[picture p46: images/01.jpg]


### 12. 自慢する
完成しましたら、ぜひSNSなどに写真を投稿頂ければと思います。  
Twitterのハッシュタグは`#Radialex`を付けていただけば幸いです。  
キットを組み立てた感想や、キーボードを使った所感などをお待ちしております！  

また、毎週日曜日の１9時より実施されている[#KEEP_PD](https://twitter.com/hashtag/KEEB_PD?f=live)に投稿頂くこともオススメです。  
開催の告知は[@KEEB_PD](https://twitter.com/KEEB_PD)にて行われております。

ご不明な点などございましたら、[@takashicompany](https://twitter.com/takashicompany)にメンションやDM頂ければと思います！

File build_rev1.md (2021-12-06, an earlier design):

# Radialex Rev1の組み立て方

## 必要な部品

### キットに同梱されているもの
|部品|個数|備考|
|:--|:--|:--|
|PCB|1|リードタイプと表面実装のダイオードに対応。|
|トッププレート|1||
|ボトムプレート|1||
|ダイオード（リードタイプ)|45||
|m2スペーサー(7mm)|8||
|m2ネジ(4mm)|8||
|m2ネジ(8mm)|4||
|m2ネジ(18mm)4||
|リセットスイッチ|1||
|MXソケット|1||
|滑り止めシール|6||

### 別途用意するもの
|部品|個数|備考|
|:--|:--|:--|
|キースイッチ|45|Cherry MX互換のもの。|
|キーキャップ|45|全て1u。Chery MX互換のもの。|
|Pro Micro|1||
|USBケーブル|1|Pro MicroとPCを接続します。|

### オプション
|部品|個数|備考|
|:--|:--|:--|
|コンスルー|2|12pin、13pinに対応しておりますのでMCU(Pro Micro)にあわせて選択が可能です。|
|MXソケット|44|中央のキー以外は、キースイッチのはんだ付け/MXソケットによる挿し込みの両方に対応。|
|LED(SK6812MINI-E)|2|中央のキーとキーボード手前側の穴をバックライトで光らせることができます。|
|LED(WS2812B)|10|アンダーグロウライトとしてキーボードの底面を光らせることができます。|

## 組みたて方

### 1. PCBの表裏を確認する

表  


裏  


### 2. ダイオードをはんだづけする

プリントにあわせてダイオードの向き(端に黒線がついているもの)を確認します。  
スルーホール型のダイオード、表面実装型のダイオードの両方に対応しております。  


ダイオードを穴に通るように折り曲げます。  


はんだ付けを行います。  


ニッパーで足を切る際は、可能な限り平坦になるようにすると後の作業が楽に進めます。  


全部で45箇所となります。  


### 3. 中央のキーのMXソケットの取り付け

中央のキーのみMXソケットでキースイッチを固定します。  


MXソケット  


MXソケットのはんだ付け部分の片方に事前にはんだを載せておきます。  


ピンセットでMXソケットを抑えながら事前に載せたはんだを溶かしながらMXソケットとPCBをはんだ付けします  


もう片方もはんだ付けを行います。  


### 4. リセットスイッチの取り付け

リセットスイッチの取り付け場所はPCBの裏面中央のやや手前側です。  


リセットスイッチがPCBの裏面から押せるように穴に通します。  


表面からはんだ付けを行います。この際、可能な限り平坦になるようにニッパーで切ると後の作業がスムーズに行えます。  


### 5. トッププレートとキースイッチの取り付け

トッププレートやボトムプレート、中央プレートはアクリルの保護シートが貼ってるので、組み立てる際に剥がしてください。  


製造の工程上、模様が発生している可能性がありますが、ご理解いただけますと幸いです。  


PCBにトッププレートを載せます。  


トッププレートにキースイッチを取り付け、はんだ付けもしくはMXソケットへの差し込みを行います。  


### 6. 中央プレートの取り付け

中央プレートは二種類あります。  


18mmのネジとスペーサーを用います。  


PCBの裏側から、スペーサーでネジと中央プレートを取り付けます。  


表面は下図のようになります。  


### 7. Pro Microの取り付け

Pro Microを取り付けます。  
PCBはコンスルーに対応しております。  


PCBの裏面にPro Microを取り付けます。  
Pro Microを取り付ける際に、ピンの位置を留意ください。(BLE Micro Proなどで使えるように13ピンになっております)  
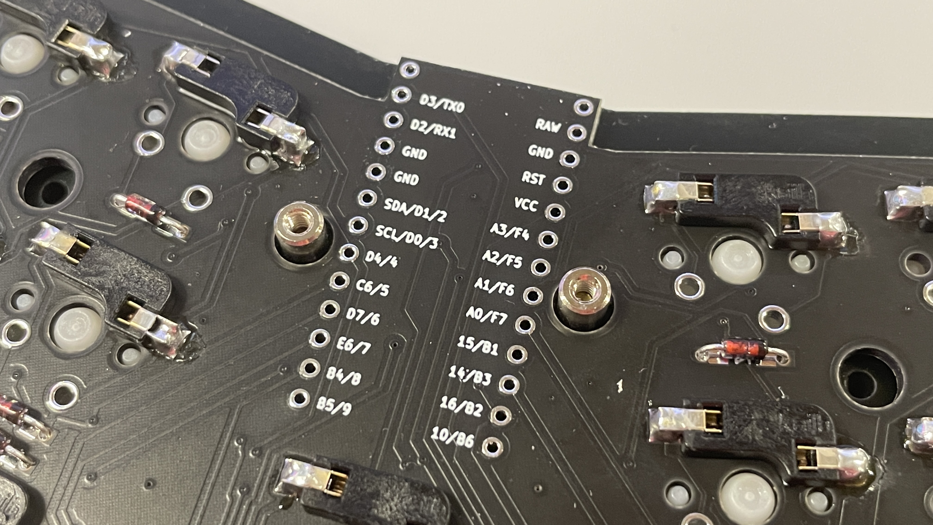
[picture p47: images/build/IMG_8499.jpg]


下図のように取り付けられれば成功です。  


### 8. ファームウェアの用意と確認

[Remap](https://remap-keys.app/catalog/IxsMPjShxAP0NbiQGbKQ/firmware)からVIAのファームウェアを書き込むことが可能です。  


Remapの使い方は[千葉千夏/あずさんの記事](https://note.com/azulee/n/n8557fdfbc679#MkVkQ)で説明されております。

ファームウェアのソースコードは[こちら](https://github.com/qmk/qmk_firmware/pull/14949)です。

VIAのファームウェアを書き込んだ状態で[Remap](https://remap-keys.app/)からキーマップを変更できます。  


### 9. LEDの取り付け(オプション)

Radialexでは、2種類のLEDを搭載できます。  
1-2番はバックライト(SK6812MINI-E)、3番から12番まではアンダーグロウ(WS2812B)となります。  


バックライトのLEDを付ける際はシルクで塗られたところにGND(LEDの角が欠けている部分)が来るように配置します。  
事前にはんだを乗せておくのが良いです。  


4箇所をはんだ付けします。  


中央のキースイッチと手前の穴が光ります。  


アンダーグロウも同様に、シルクの三角の部分にGND(LEDが角が欠けている部分)が来るように配置します。  


同じく4箇所をはんだ付けします。  


12箇所が光るかを確認します。  


### 10. ボトムプレートの取り付け

最後にボトムプレートを取り付けます。  


トッププレート側は8mmのネジ、ボトムプレート側は4mmのネジでスペーサーを赤丸の位置に留めます。  


ボトムプレートを取り付けたら滑り止めシールを底面に取り付けます。


赤丸の位置に貼るとグラつきが少ないです。  


### 11. キーキャップを取り付ける

最後にキーキャップを取り付けて完成です。  


### 11. 自慢する
完成しましたら、ぜひSNSなどに写真を投稿頂ければと思います。  
Twitterのハッシュタグは`#Radialex`を付けていただけば幸いです。  
キットを組み立てた感想や、キーボードを使った所感などをお待ちしております！  

また、毎週日曜日の１9時より実施されている[#KEEP_PD](https://twitter.com/hashtag/KEEB_PD?f=live)に投稿頂くこともオススメです。  
開催の告知は[@KEEB_PD](https://twitter.com/KEEB_PD)にて行われております。

ご不明な点などございましたら、[@takashicompany](https://twitter.com/takashicompany)にメンションやDM頂ければと思います！

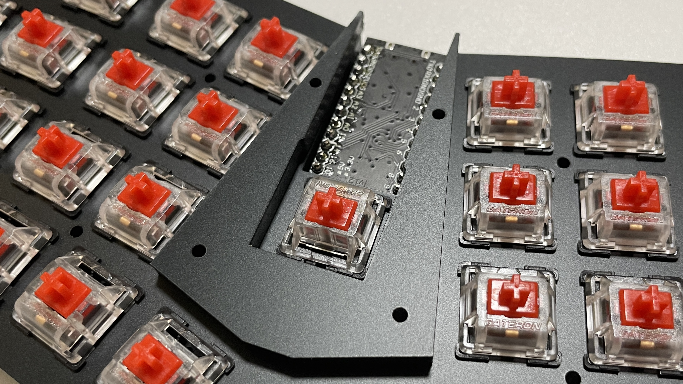
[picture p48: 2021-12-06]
images/build/IMG_9216.jpg

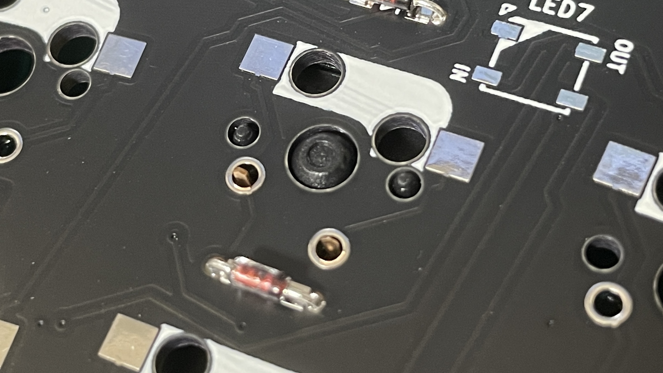
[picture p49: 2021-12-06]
images/build/IMG_9210.jpg

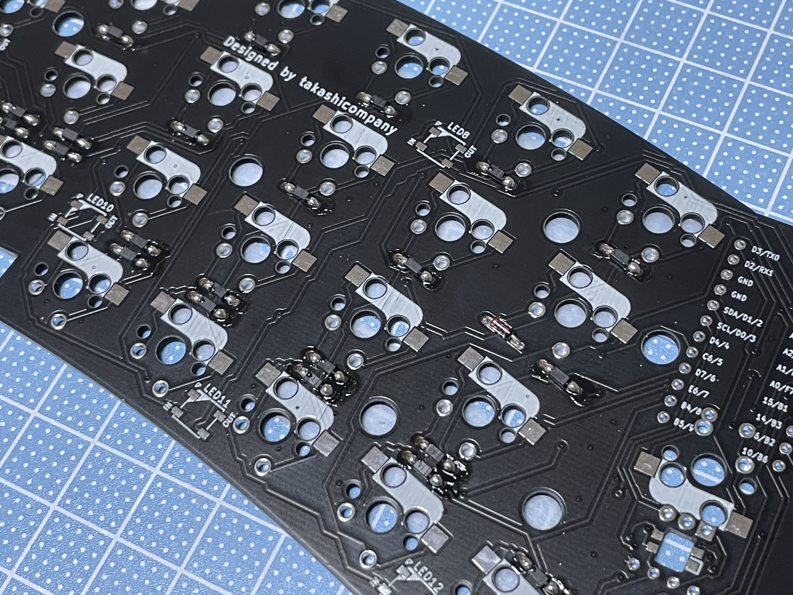
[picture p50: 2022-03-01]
images/build/IMG_8012.jpg

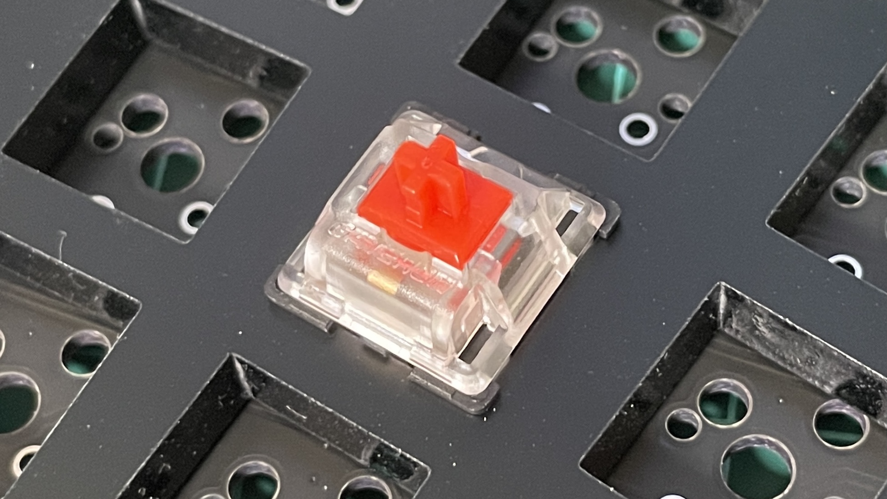
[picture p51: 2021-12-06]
images/build/IMG_9209.jpg

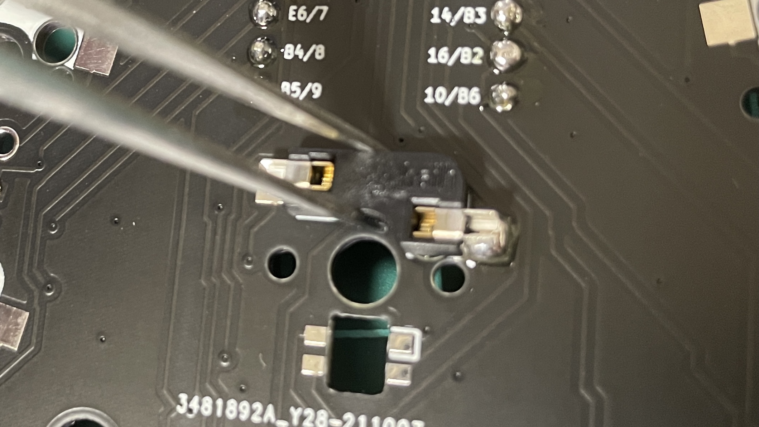
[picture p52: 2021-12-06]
images/build/IMG_9200.jpg

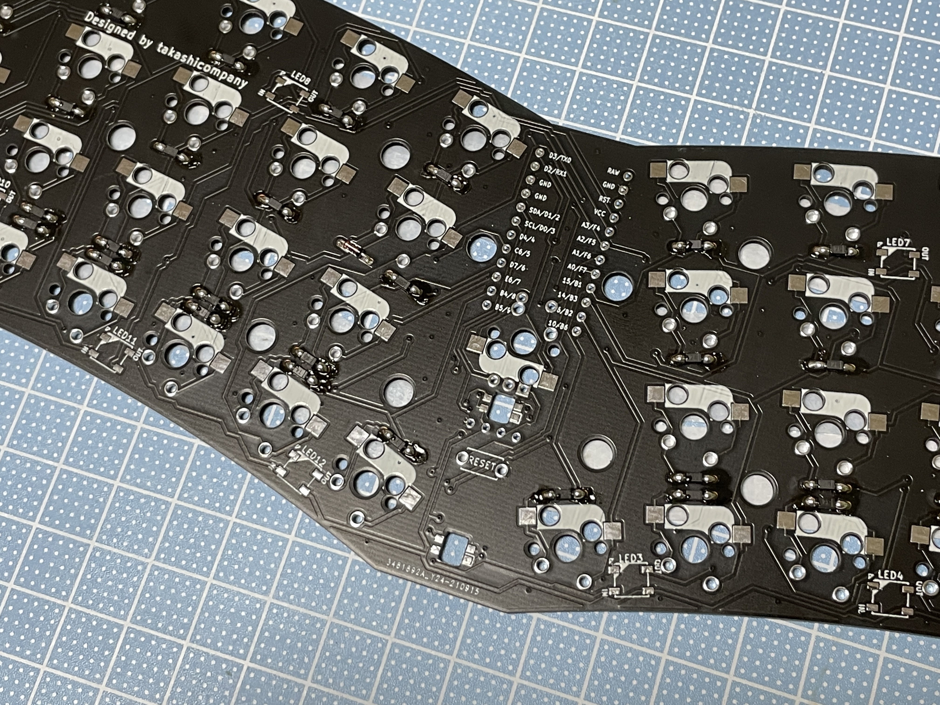
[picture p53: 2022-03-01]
images/build/IMG_8011.jpg

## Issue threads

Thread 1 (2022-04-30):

LEDの制御をD2にする

takashicompany, 2022-04-30:
ファームウェアのソースコード : https://github.com/takashicompany/qmk_firmware/tree/radialex/fix-d3/keyboards/takashicompany/radialex

takashicompany, 2022-04-30:
ファームウェアのzipファイル [takashicompany_radialex_via.hex.zip](https://github.com/takashicompany/radialex/files/8597011/takashicompany_radialex_via.hex.zip)

takashicompany, 2022-05-01:
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

takashicompany, 2022-05-01:
[takashicompany_radialex_default.hex.zip](https://github.com/takashicompany/radialex/files/8598162/takashicompany_radialex_default.hex.zip)

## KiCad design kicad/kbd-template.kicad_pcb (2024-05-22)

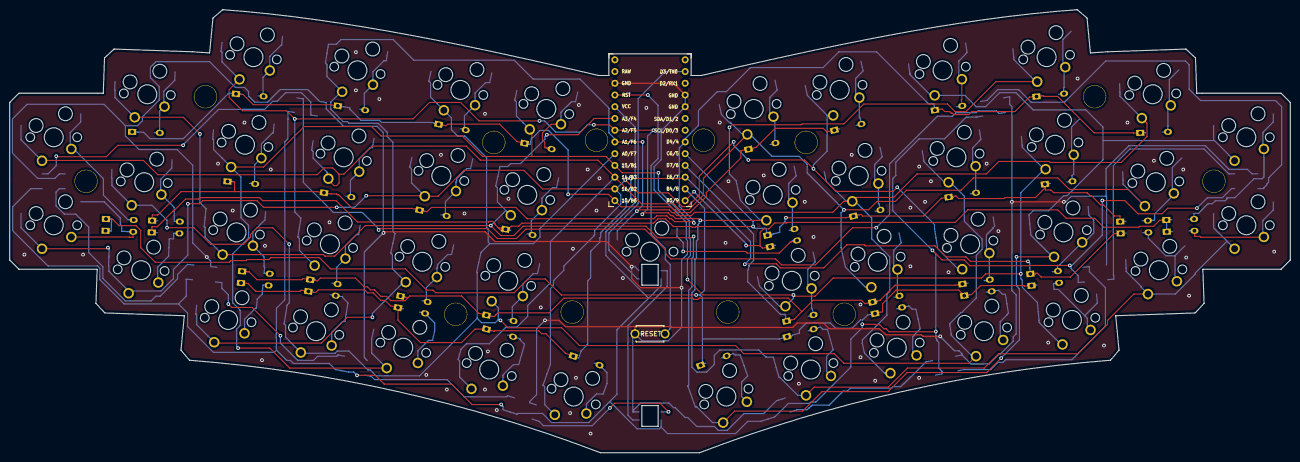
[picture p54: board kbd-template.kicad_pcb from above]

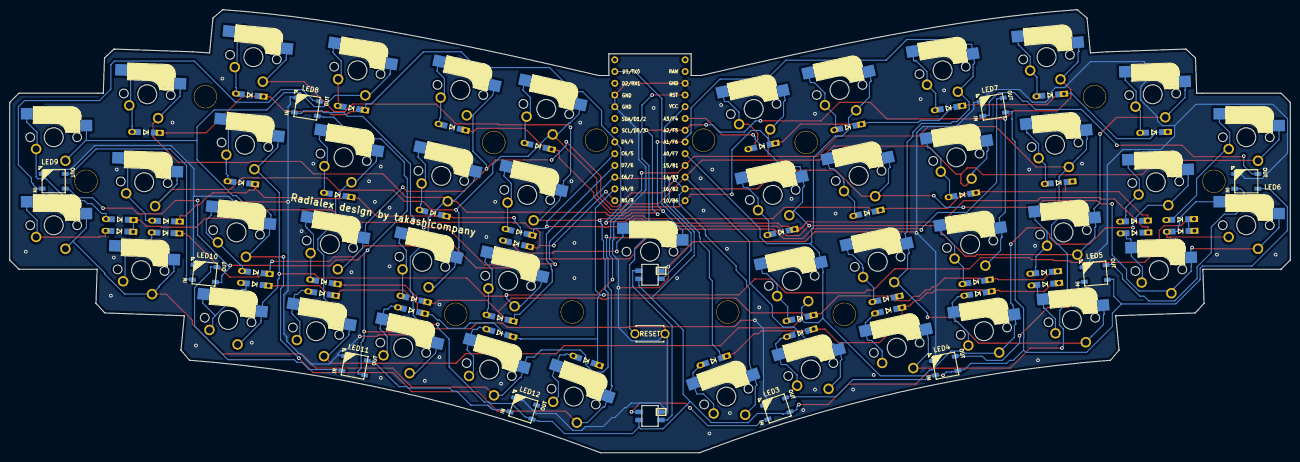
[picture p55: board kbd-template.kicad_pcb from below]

Board: 2 copper layers, 277.2 x 95.9 mm, 116 parts (56 on the bottom side), 74 nets.

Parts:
D1, D2, D3, D4, D5, D6, D7, D8, D9, D10, D11, D12, D13, D14, D15, D16, D17, D18, D19, D20, D21, D22, D23, D24, D25, D26, D27, D28, D29, D30, D31, D32, D33, D34, D35, D36, D37, D38, D39, D40, D41, D42, D43, D44, D45: DIODE; D3_TH_SMD_v2
Hole01, Hole02, Hole03, Hole04, Hole05, Hole06, Hole07, Hole08, Hole09, Hole10, Hole11, Hole12: Val**; HOLE
LED1, LED2: YS-SK6812MINI-E; SK6812MINI_bg
LED3, LED4, LED5, LED6, LED7, LED8, LED9, LED10, LED11, LED12: WS2812B
RESET_SW1: SW_Push; ResetSW
SW1, SW2, SW3, SW4, SW5, SW6, SW7, SW8, SW9, SW10, SW11, SW12, SW13, SW14, SW15, SW16, SW17, SW18, SW19, SW20, SW21, SW22, SW23, SW24, SW25, SW26, SW27, SW28, SW29, SW30, SW31, SW32, SW33, SW34, SW35, SW36, SW37, SW38, SW39, SW40, SW41, SW42, SW43, SW44: SW_Push; CherryMX_TH-Hotswap
SW45: SW_Push; CherryMX_Hotswap
U1: ProMicro; ProMicro_v3.5_13pin_print-inside

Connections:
GND: LED1.3, LED2.3, LED3.3, LED4.3, LED5.3, LED6.3, LED7.3, LED8.3, LED9.3, LED10.3, LED11.3, LED12.3, RESET_SW1.2, U1.3, U1.4, U1.23
unnamed: D1.2, SW1.2
unnamed: D2.2, SW2.2
unnamed: D3.2, SW3.2
unnamed: D4.2, SW4.2
unnamed: D5.2, SW5.2
unnamed: D6.2, SW6.2
unnamed: D7.2, SW7.2
unnamed: D8.2, SW8.2
unnamed: D9.2, SW9.2
unnamed: D10.2, SW10.2
unnamed: D11.2, SW11.2
unnamed: D12.2, SW12.2
unnamed: D13.2, SW13.2
unnamed: D14.2, SW14.2
unnamed: D15.2, SW15.2
unnamed: D16.2, SW16.2
unnamed: D17.2, SW17.2
unnamed: D18.2, SW18.2
unnamed: D19.2, SW19.2
unnamed: D20.2, SW20.2
unnamed: D21.2, SW21.2
unnamed: D22.2, SW22.2
unnamed: D23.2, SW23.2
unnamed: D24.2, SW24.2
unnamed: D25.2, SW25.2
unnamed: D26.2, SW26.2
unnamed: D27.2, SW27.2
unnamed: D28.2, SW28.2
unnamed: D29.2, SW29.2
unnamed: D30.2, SW30.2
unnamed: D31.2, SW31.2
unnamed: D32.2, SW32.2
unnamed: D33.2, SW33.2
unnamed: D34.2, SW34.2
unnamed: D35.2, SW35.2
unnamed: D36.2, SW36.2
unnamed: D37.2, SW37.2
unnamed: D38.2, SW38.2
unnamed: D39.2, SW39.2
unnamed: D40.2, SW40.2
unnamed: D41.2, SW41.2
unnamed: D42.2, SW42.2
unnamed: D43.2, SW43.2
unnamed: D44.2, SW44.2
unnamed: D45.2, SW45.2
unnamed: LED1.2, LED2.4
unnamed: LED2.2, LED3.4
unnamed: LED3.2, LED4.4
unnamed: LED4.2, LED5.4
unnamed: LED5.2, LED6.4
unnamed: LED6.2, LED7.4
unnamed: LED7.2, LED8.4
unnamed: LED8.2, LED9.4
unnamed: LED10.2, LED11.4
unnamed: LED9.2, LED10.4
unnamed: LED11.2, LED12.4
VCC: LED1.1, LED2.1, LED3.1, LED4.1, LED5.1, LED6.1, LED7.1, LED8.1, LED9.1, LED10.1, LED11.1, LED12.1, U1.21
col1: SW1.1, SW8.1, SW15.1, SW22.1, SW29.1, SW36.1, SW43.1, U1.20
col2: SW2.1, SW9.1, SW16.1, SW23.1, SW30.1, SW37.1, SW44.1, U1.19
col3: SW3.1, SW10.1, SW17.1, SW24.1, SW31.1, SW38.1, SW45.1, U1.18
col4: SW4.1, SW11.1, SW18.1, SW25.1, SW32.1, SW39.1, U1.17
col5: SW5.1, SW12.1, SW19.1, SW26.1, SW33.1, SW40.1, U1.16
col6: SW6.1, SW13.1, SW20.1, SW27.1, SW34.1, SW41.1, U1.15
col7: SW7.1, SW14.1, SW21.1, SW28.1, SW35.1, SW42.1, U1.14
led: LED1.4, U1.1
reset: RESET_SW1.1, U1.22
row1: D1.1, D2.1, D3.1, D4.1, D5.1, D6.1, D7.1, U1.13
row2: D8.1, D9.1, D10.1, D11.1, D12.1, D13.1, D14.1, U1.7
row3: D15.1, D16.1, D17.1, D18.1, D19.1, D20.1, D21.1, U1.8
row4: D22.1, D23.1, D24.1, D25.1, D26.1, D27.1, D28.1, U1.9
row5: D29.1, D30.1, D31.1, D32.1, D33.1, D34.1, D35.1, U1.10
row6: D36.1, D37.1, D38.1, D39.1, D40.1, D41.1, D42.1, U1.11
row7: D43.1, D44.1, D45.1, U1.12

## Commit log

2021-10-25 画像を追加
2021-10-29 一旦コミット
2021-10-29 さらに追加
2021-10-29 画像を載せた
2021-10-30 ちょっと修正
2021-10-30 モノを書いた。
2021-10-30 同梱物を確認
2021-11-02 コンスルーの個数を修正
2021-12-06 rev1とrev2
2021-12-06 リンク先に組み立て方を記載
2021-12-16 リネーム
2022-01-09 誤字を修正
2022-02-24 ダイオードを修正
2022-03-01 写真を追加
2022-04-29 データーを追加
2022-05-03 LED穴のボトムプレート
2022-05-03 ボトムプレートにバリエーションを追加
2022-05-03 ケースを更新
2022-05-10 画像を更新
2022-05-31 遊舎工房のアクリルカットサービスで使ったデータ
2022-07-23 遊舎工房 A4 3mm
2022-09-03 使ってないデータを削除
2022-09-11 ケースに余計なデータ入ってたので消す
2022-09-11 40mm ロゴ
